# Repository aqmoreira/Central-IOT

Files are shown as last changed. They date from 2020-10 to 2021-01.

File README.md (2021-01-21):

# Central-IOT
Central Semafórica IOT - Projeto Hardware e Software UNIVESP

Projeto focado em explorar e praticar conceitos desenvolvidos no curso de Engenharia da Computação da UNIVESP, apresentado como projeto de TCC em Grupo.
<br>
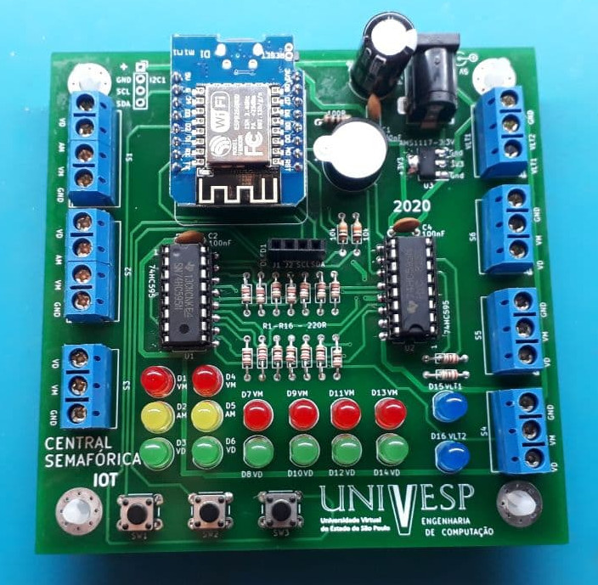
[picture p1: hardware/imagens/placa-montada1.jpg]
Placa Central IOT


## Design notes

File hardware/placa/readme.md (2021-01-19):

A placa foi desenvolvida com Kicad 5.1.6
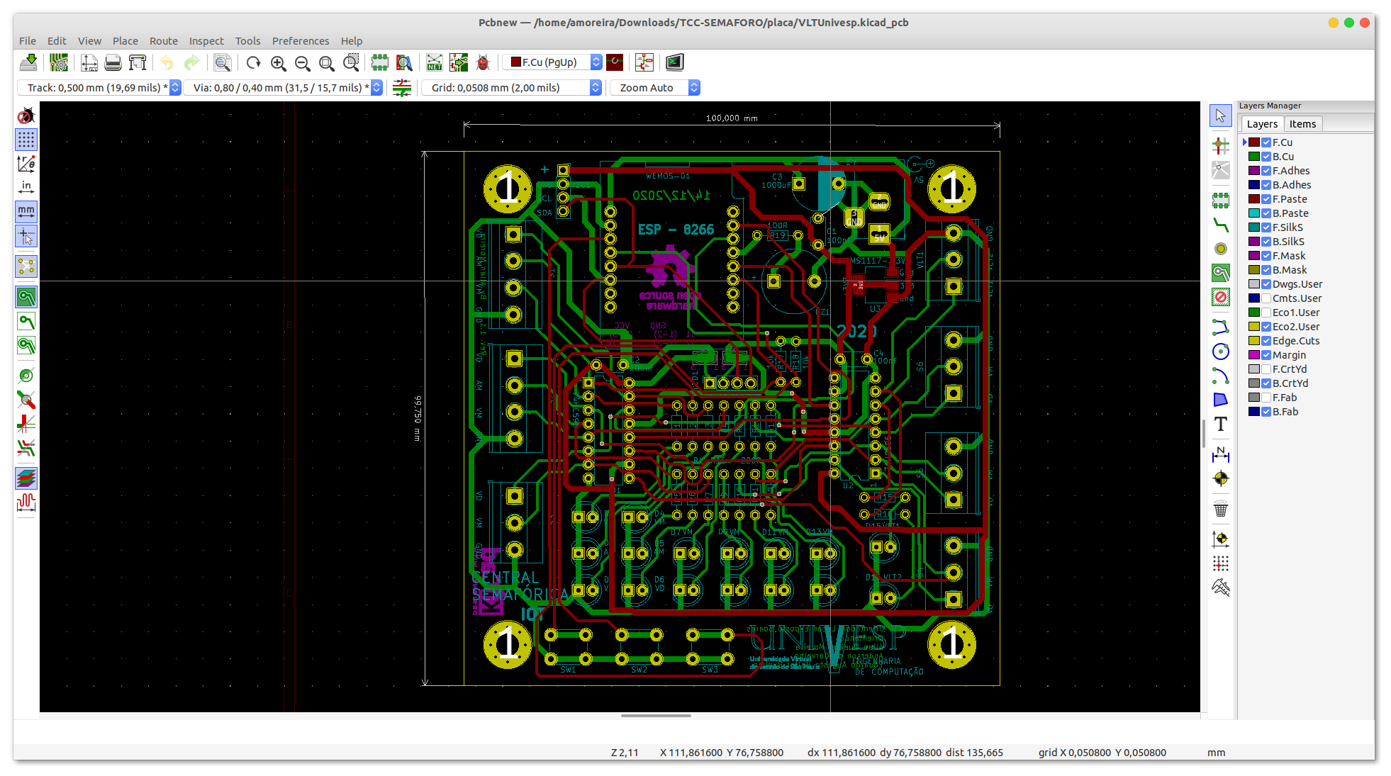
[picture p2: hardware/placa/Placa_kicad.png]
Imagem da Placa Kicad


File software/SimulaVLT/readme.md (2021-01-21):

Com objetivo de realizar os testes e simulação das diversas situações foi desenvolvido um simulador em HTML5.<br>
A implementação faz comunicação com um servidor Mqtt, simulando a movimentação do VLT pelo cruzamento.<br>
Para iniciar o simulador, realize o download dos arquivos da pasta e abra no Browser o arquivo index.html<br>

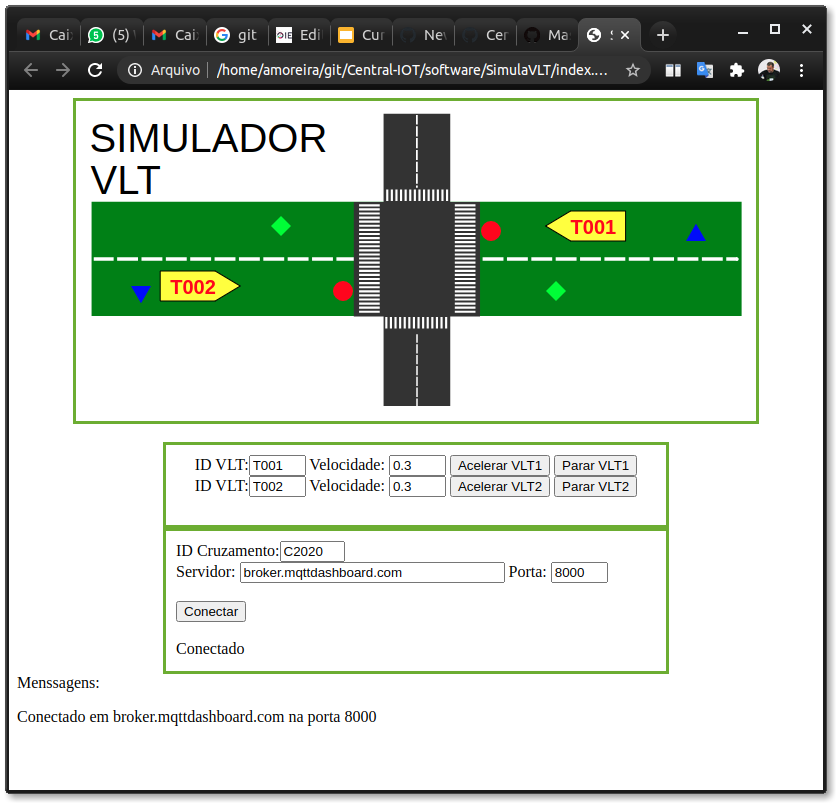
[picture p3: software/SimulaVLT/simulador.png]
Imagem da Simulador


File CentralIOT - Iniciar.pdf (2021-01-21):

1 - Instalar IDE Arduino
https://www.arduino.cc/en/software

2 - Adicionar suporte ao ESP8266,ESP32 a IDE Arduino

Abrir IDE Arduino e depois no menu Arquivo>Preferencias

Adicionar URL adicionais para gerenciamento de placas

https://arduino.esp8266.com/stable/package_esp8266com_index.json

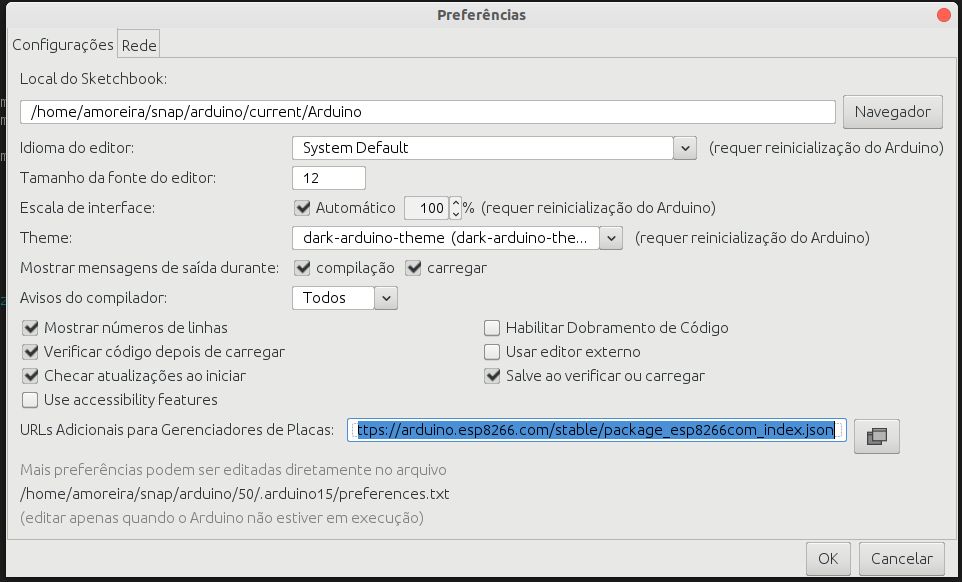
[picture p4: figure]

Aproveita e já marca as opções Mostrar mensagens de saída durante: compilação e carregar

3 - Adicionar pacote ESP8266
Menu Ferramentas > Placa:XXXX > Gerenciador de placas …

Pode informar esp no campo de filtro que vai listar apenas as relacionadas

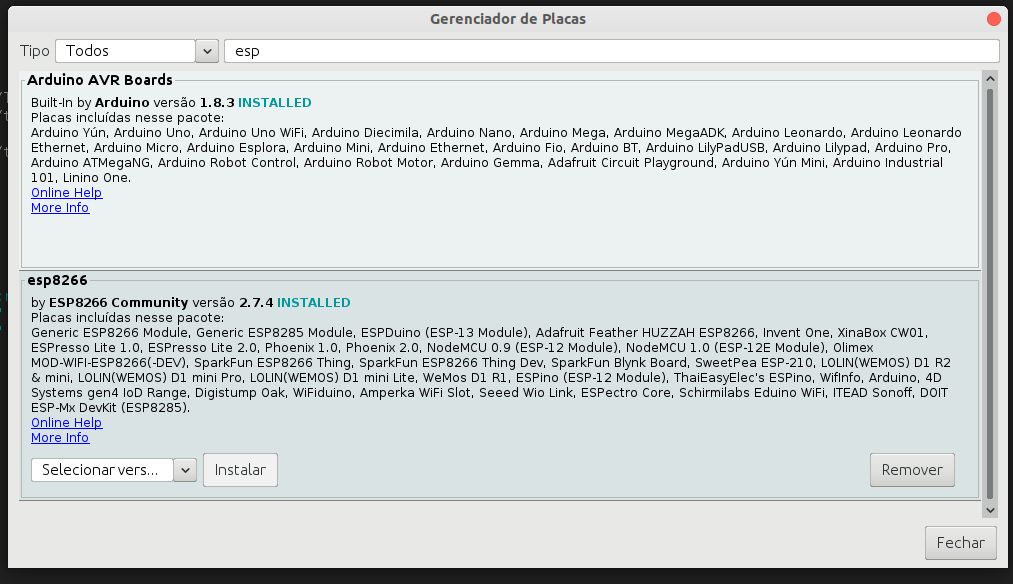
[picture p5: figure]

Deve instalar o ESP8266 Comunity, estou usando a versão 2.7.4

Ele vai carregar os pacotes para que a IDE do Arduino dê suporte aos diversos tipos de hardware do ESP.

4 - Selecionar qual placa estamos utilizando
Ferramentas -> Esp8266 2.7.4 > LOLIN (WEMOS) D1 R2 & mini

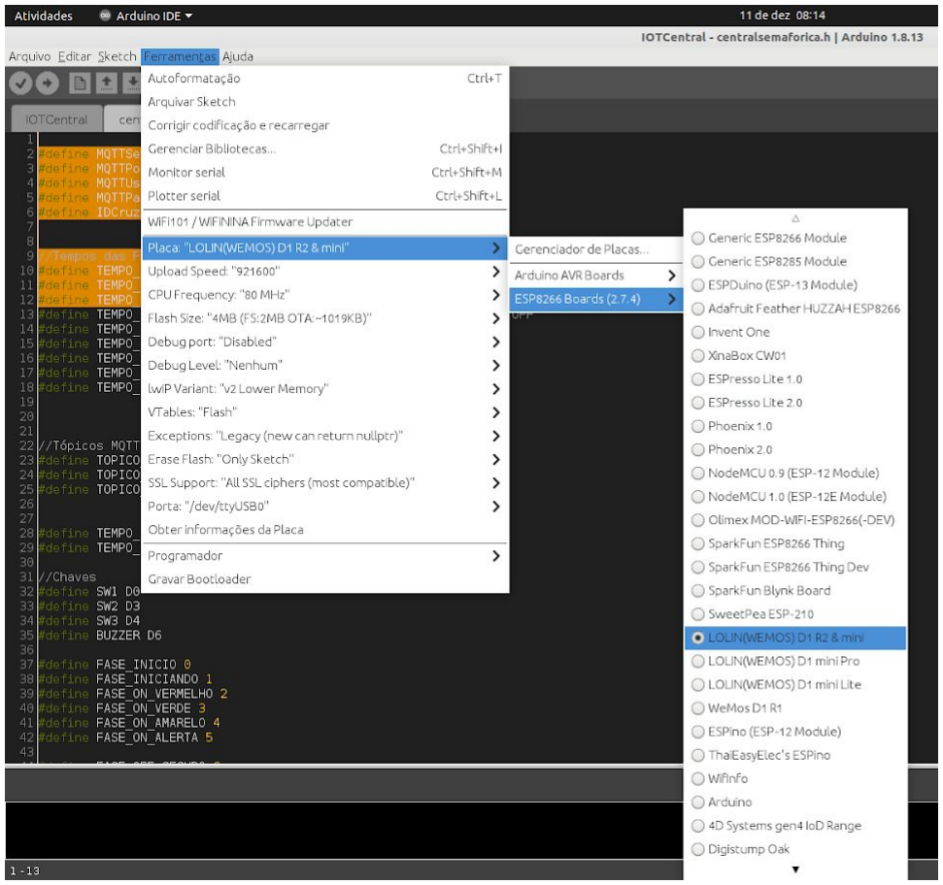
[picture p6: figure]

Esse processo faz apenas a primeira vez para selecionar a placa que está utilizando.

5 - Selecionar a porta serial.

Cada vez que conectar a placa na porta USB pode ser configurada uma porta serial virtual diferente, então deve se atentar a isso e selecionar a porta correta antes de carregar o firmware.

Ferramentas > Porta > Seleciona a porta que apareceu após você conectar

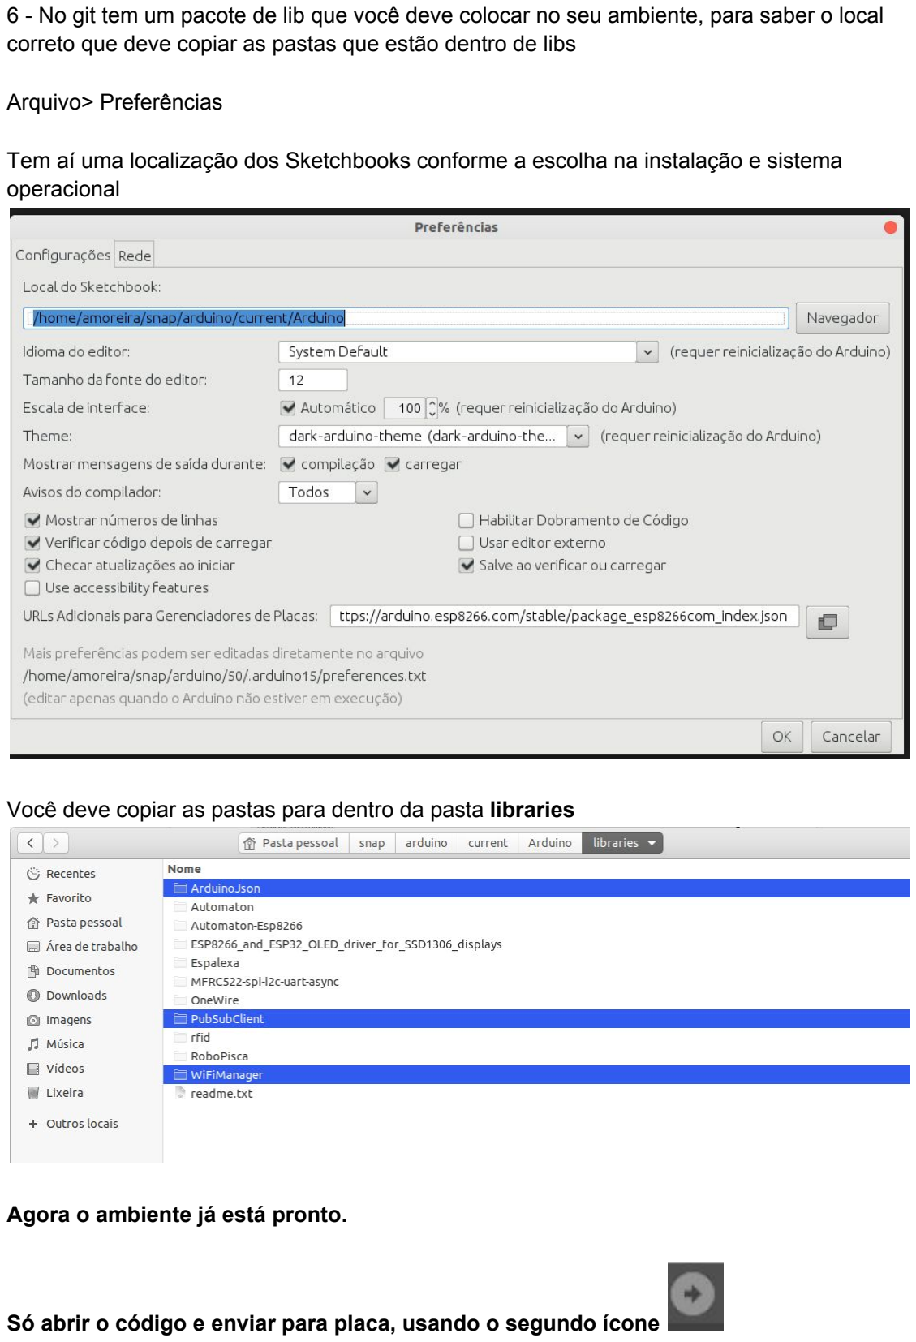
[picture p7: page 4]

6 - No git tem um pacote de lib que você deve colocar no seu ambiente, para saber o local correto que deve copiar as pastas que estão dentro de libs

Arquivo> Preferências

Tem aí uma localização dos Sketchbooks conforme a escolha na instalação e sistema operacional

Você deve copiar as pastas para dentro da pasta libraries

Agora o ambiente já está pronto.

Só abrir o código e enviar para placa, usando o segundo ícone

Fique atento na barra inferior se as mensagens com % de carregamento vai chegar a 100% ou se teremos algum erro.

Se o carregamento foi 100%, agora é reiniciar a placa no reset um pequeno botão perto do conector do cabo usb e manter pressionado a Sw1 e Sw3 para ele ligar uma rede chamada CentralIOT para vc conectar nela e fazer os ajustes da placa

Senha: univesp2020

Além dos dados da sua placa, você tem que informar id do cruzamento, por exemplo 0008, esse número vai aparecer depois no display para saber qual é o cruzamento que a placa está gerenciando

Os dados de Mqtt mantêm o padrão indicado que irá funcionar com esse servidor.

O servidor padrão você consegue acessar via browser:

http://www.hivemq.com/demos/websocket-client/?

Basta conectar e assinar os tópicos:

central/cruzamento/#
via01/+/<idcruzamento> //exemplo: via01/+/0008
via02/+/<idcruzamento>

COnectado na internet você vai ver no navegador chegando mensagem da placa em operação e para ver ela operando use o simulador abrindo a página no navegador que baixou do git

No simulador você deve colocar o idCruzamento igual da placa e conectar, e vai ver os eventos na placa, no servidor conforme o simulador opera.

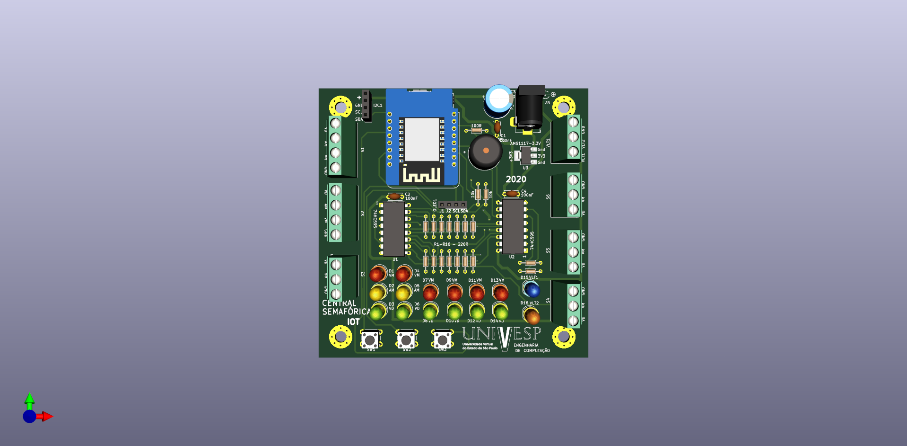
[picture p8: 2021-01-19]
hardware/placa/VLTUnivesp-frente.png

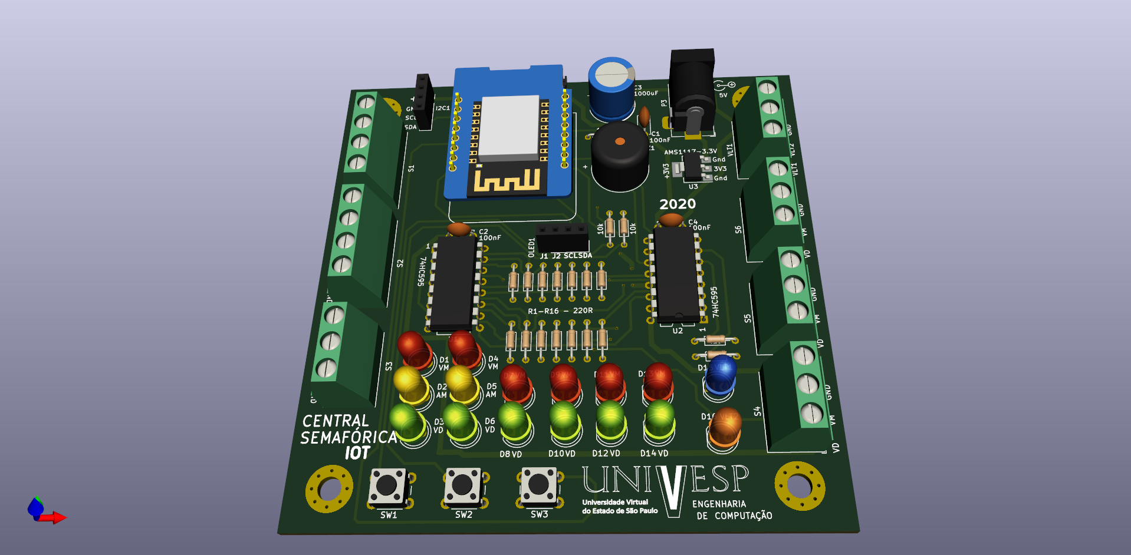
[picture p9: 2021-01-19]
hardware/placa/VLTUnivesp.png

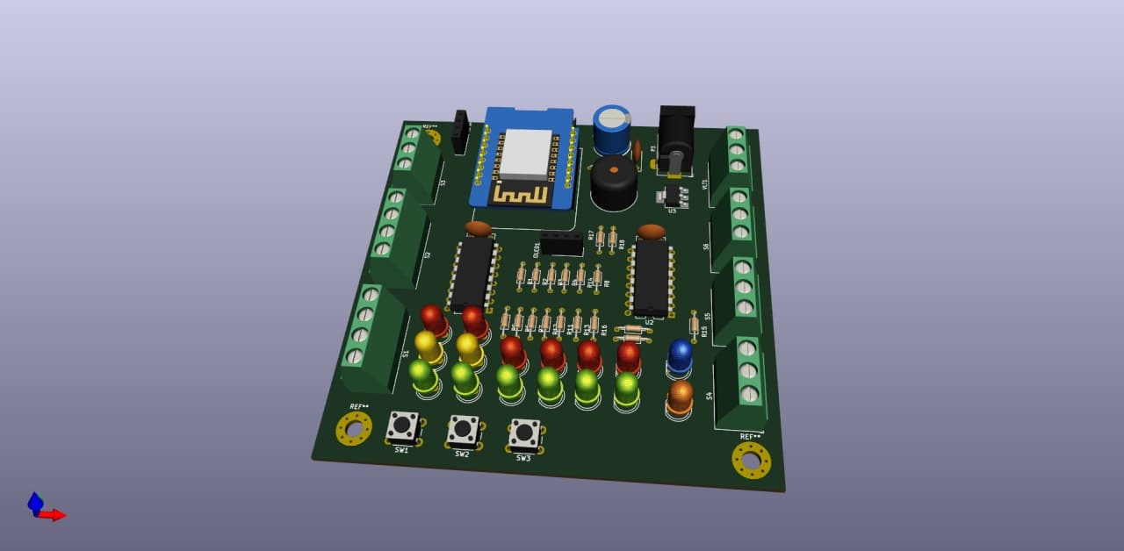
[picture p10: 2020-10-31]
hardware/imagens/central-iot-3d-kicad.jpg

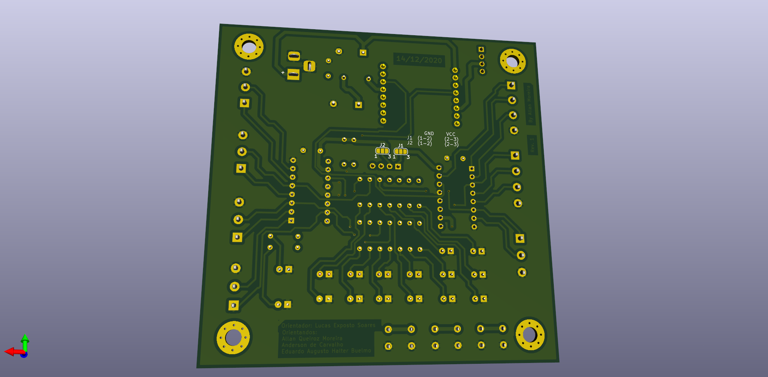
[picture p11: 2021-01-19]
hardware/placa/VLTUnivesp-verso.png

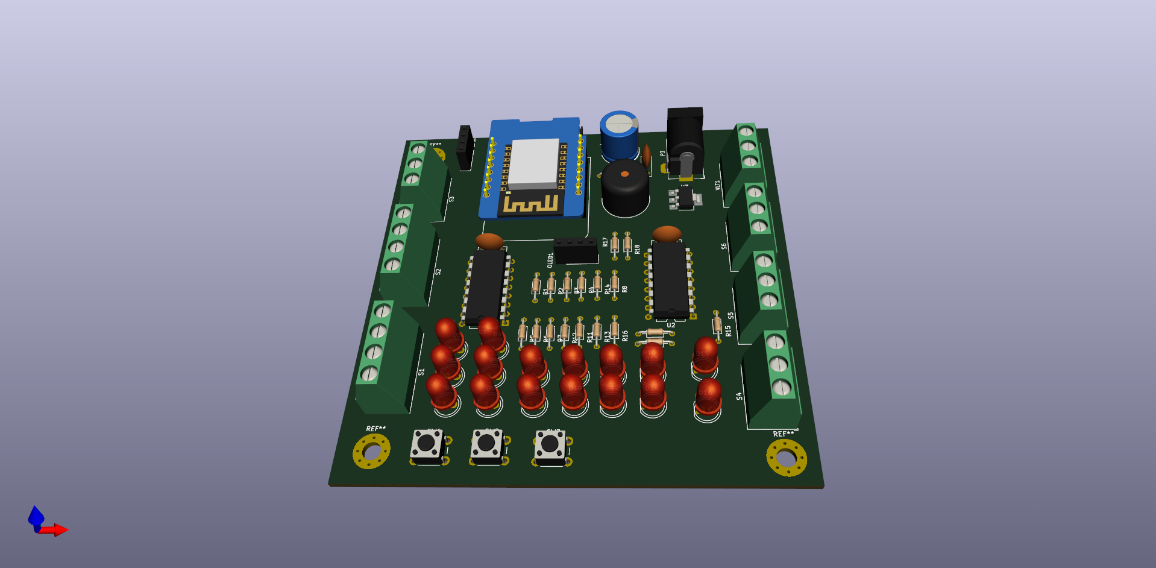
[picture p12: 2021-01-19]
hardware/placa/VLTUnivesp-frente1.png

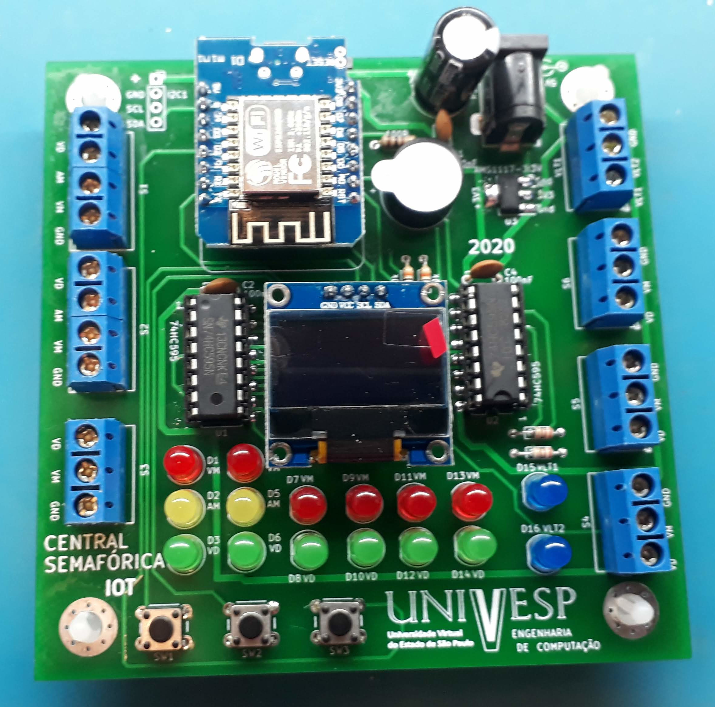
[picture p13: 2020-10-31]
hardware/imagens/placa-montada.jpg

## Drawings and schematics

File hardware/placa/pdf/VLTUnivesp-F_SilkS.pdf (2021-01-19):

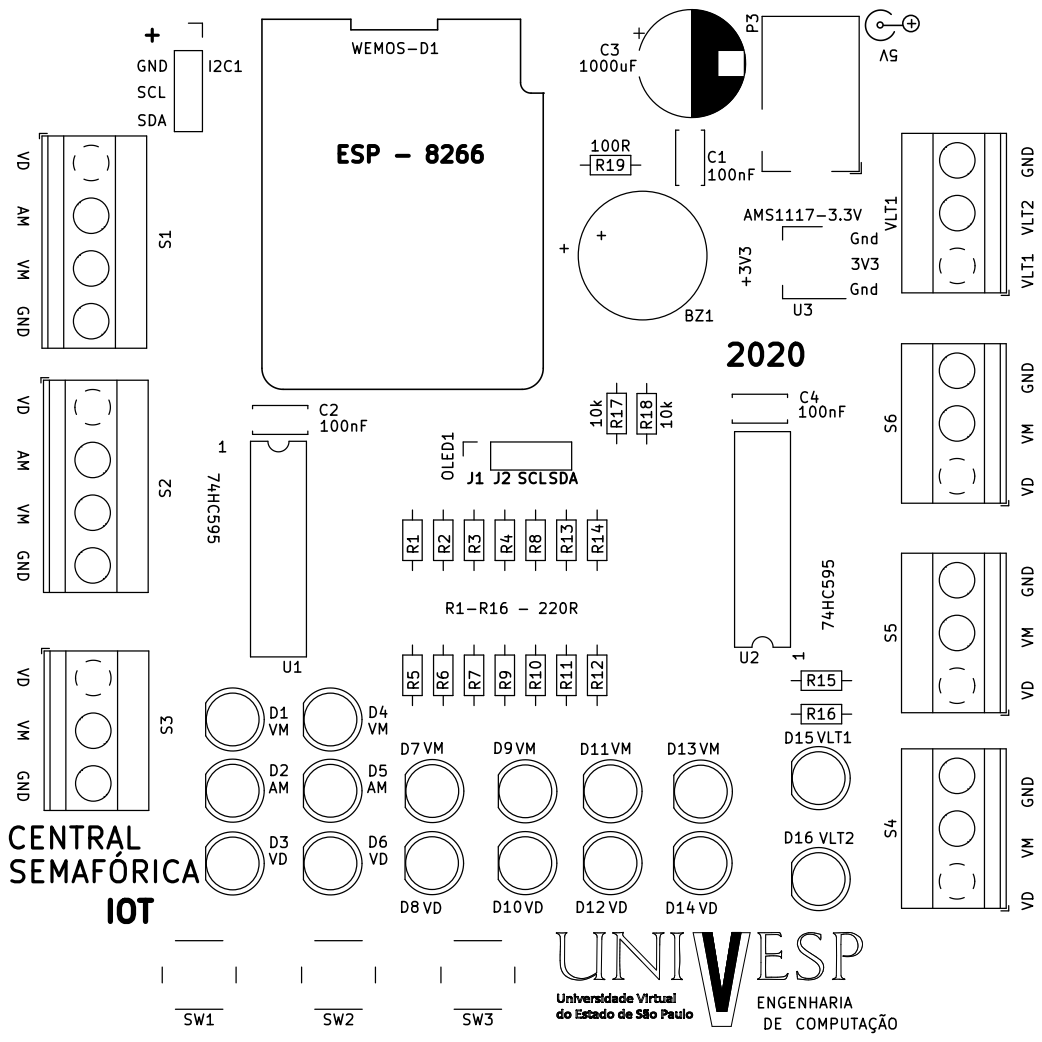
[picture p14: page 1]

VM GND VM VD VD GND VM AM GND VM AM VD

1 GND VLT2 VLT1 GND VD VM GND VM VD VD VM GND

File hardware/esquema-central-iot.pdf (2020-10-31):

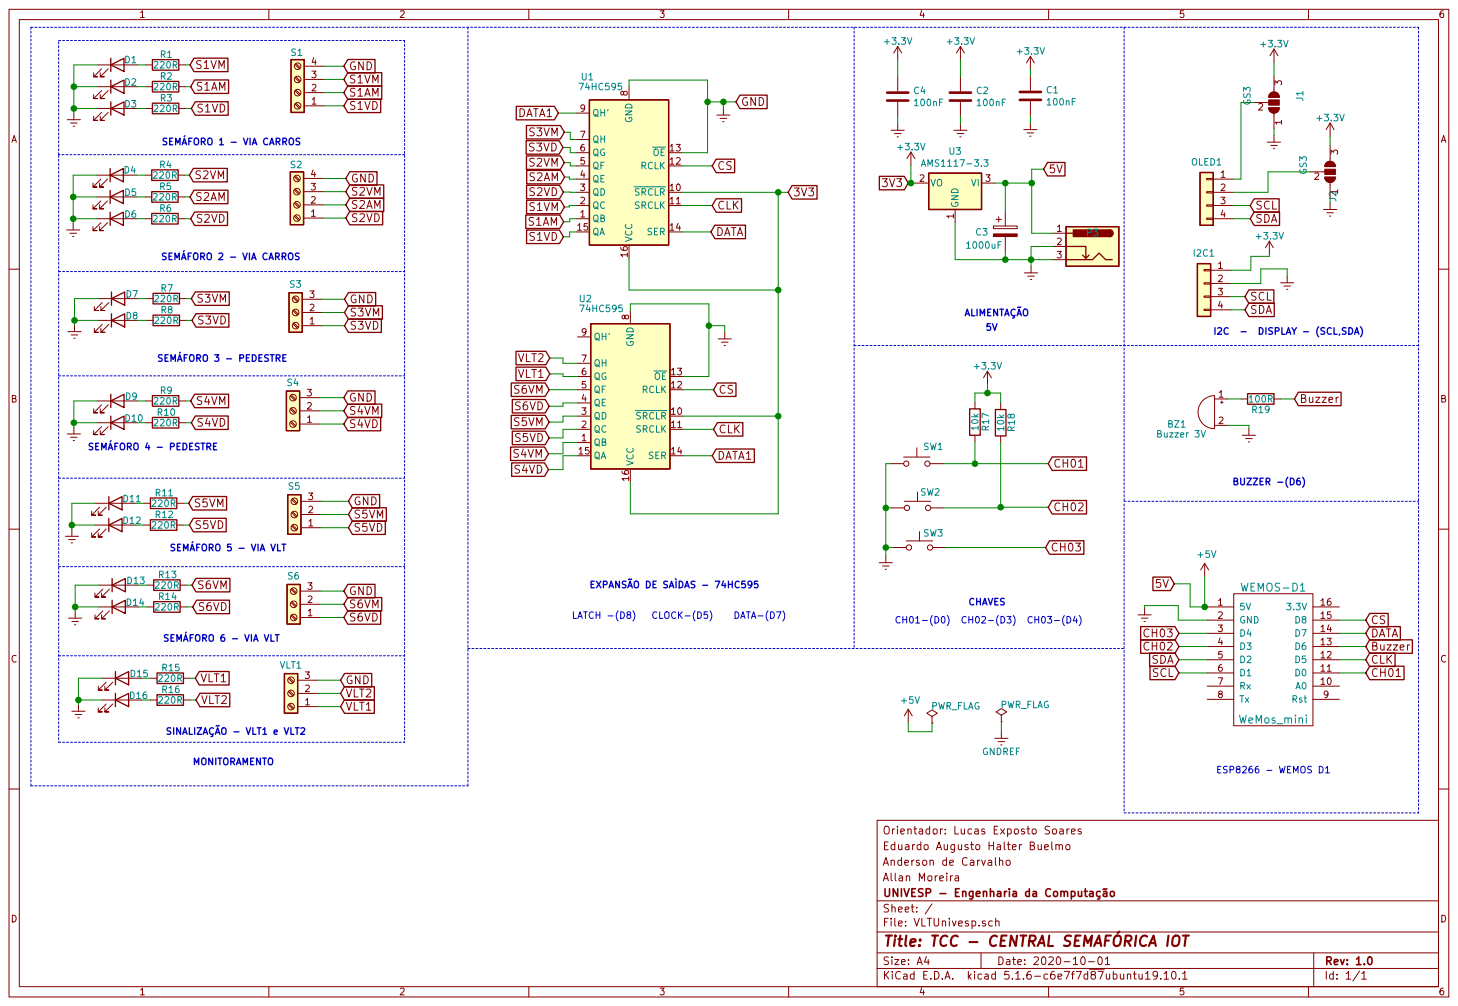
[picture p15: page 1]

SEMÁFORO 1 - VIA CARROS

SEMÁFORO 2 - VIA CARROS

SEMÁFORO 5 - VIA VLT MONITORAMENTO SEMÁFORO 6 - VIA VLT

SINALIZAÇÃO - VLT1 e VLT2

File: VLTUnivesp.sch Sheet: / UNIVESP - Engenharia da Computação Allan Moreira Anderson de Carvalho Eduardo Augusto Halter Buelmo

Id: 1/1 Title: TCC - CENTRAL SEMAFÓRICA IOT

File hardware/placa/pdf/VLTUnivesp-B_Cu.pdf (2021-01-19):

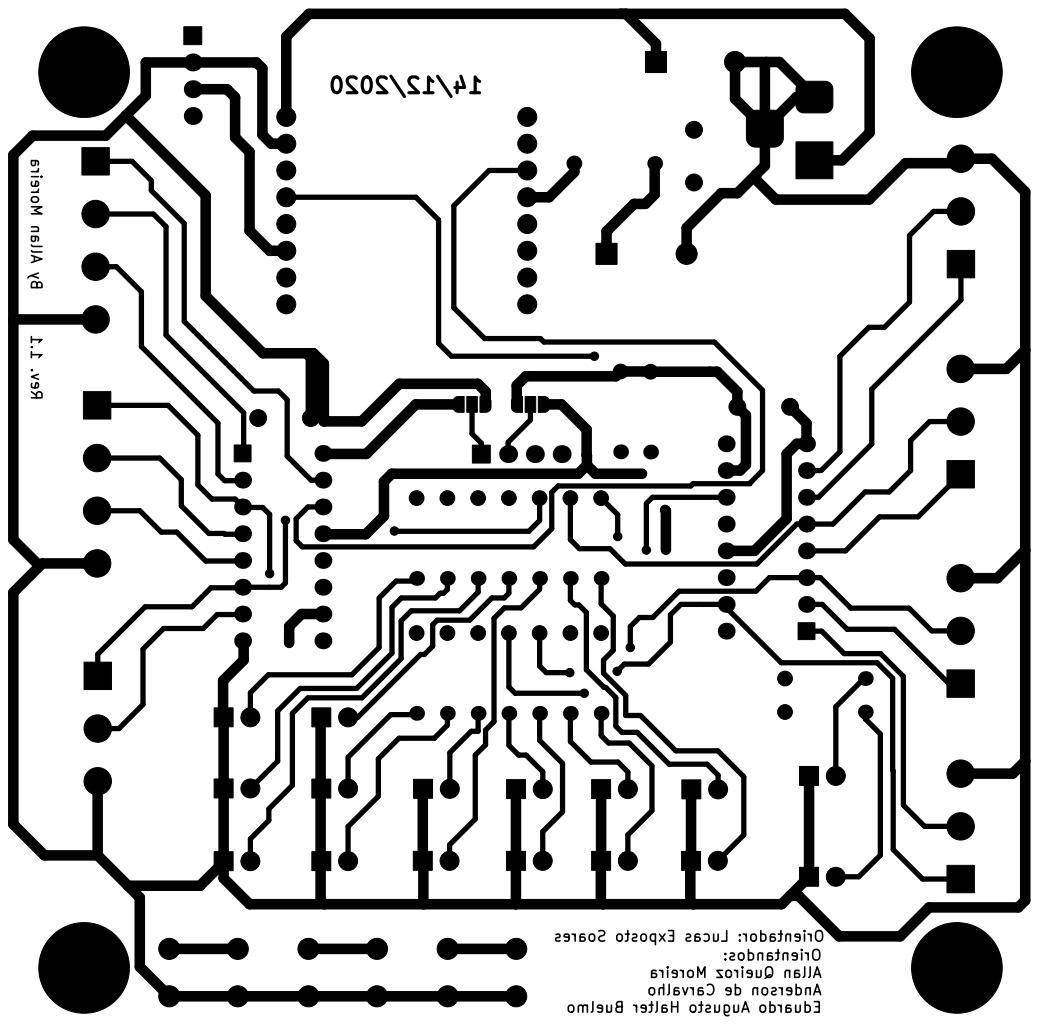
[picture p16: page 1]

14/12/2020 Rev. 1.1 By Allan Moreira Orientandos: Allan Queiroz Moreira Anderson de Carvalho Eduardo Augusto Halter Buelmo Orientador: Lucas Exposto Soares

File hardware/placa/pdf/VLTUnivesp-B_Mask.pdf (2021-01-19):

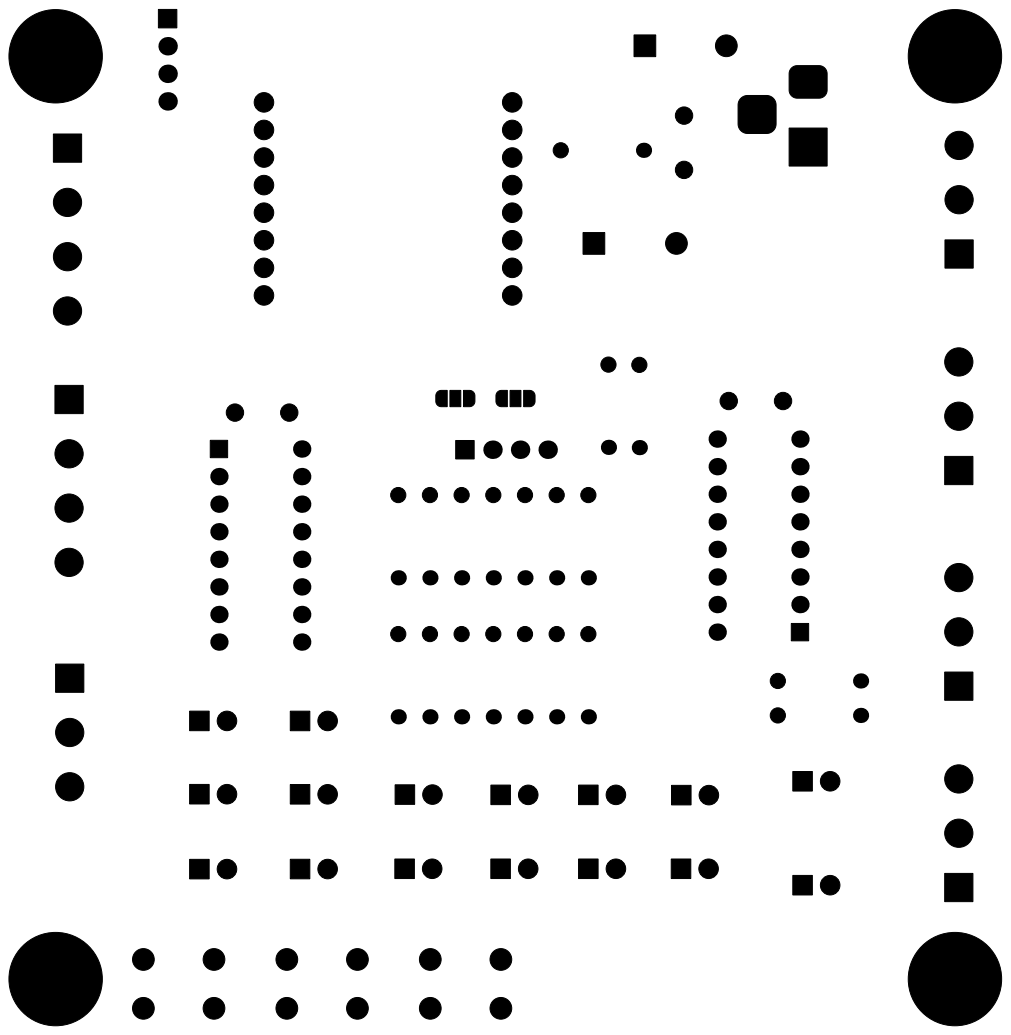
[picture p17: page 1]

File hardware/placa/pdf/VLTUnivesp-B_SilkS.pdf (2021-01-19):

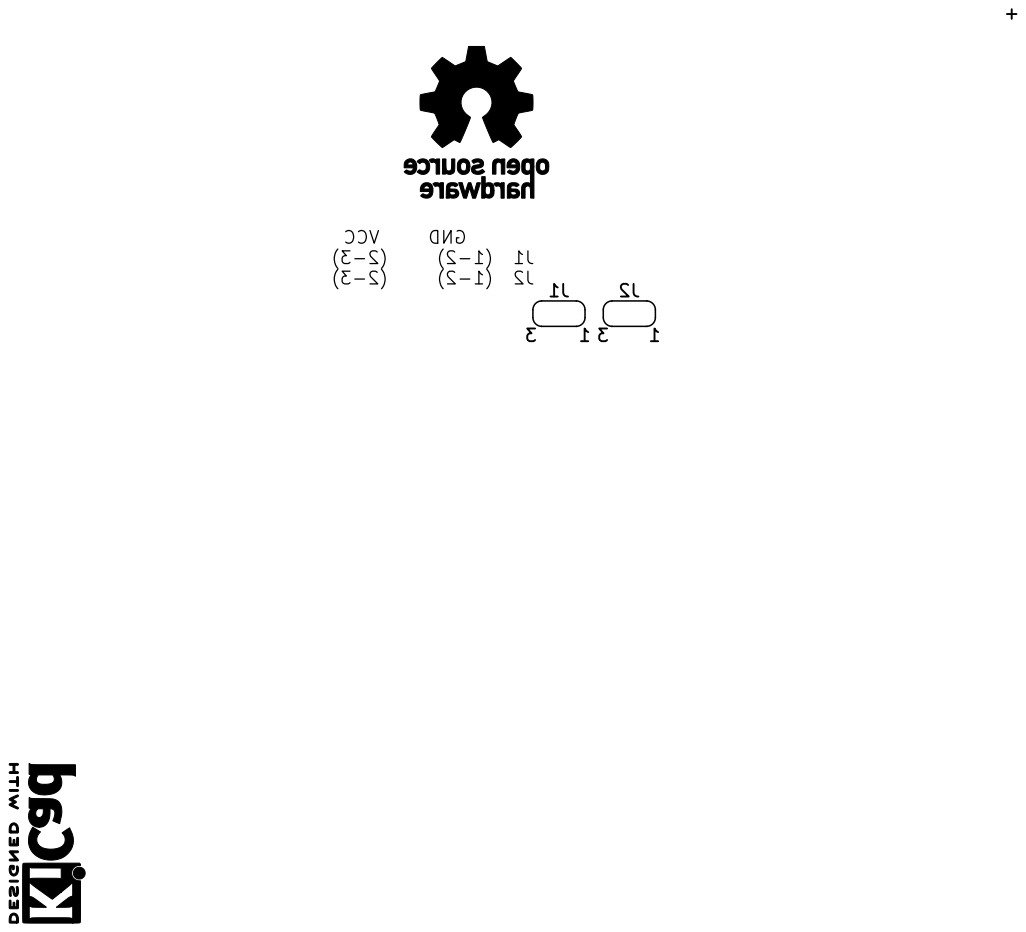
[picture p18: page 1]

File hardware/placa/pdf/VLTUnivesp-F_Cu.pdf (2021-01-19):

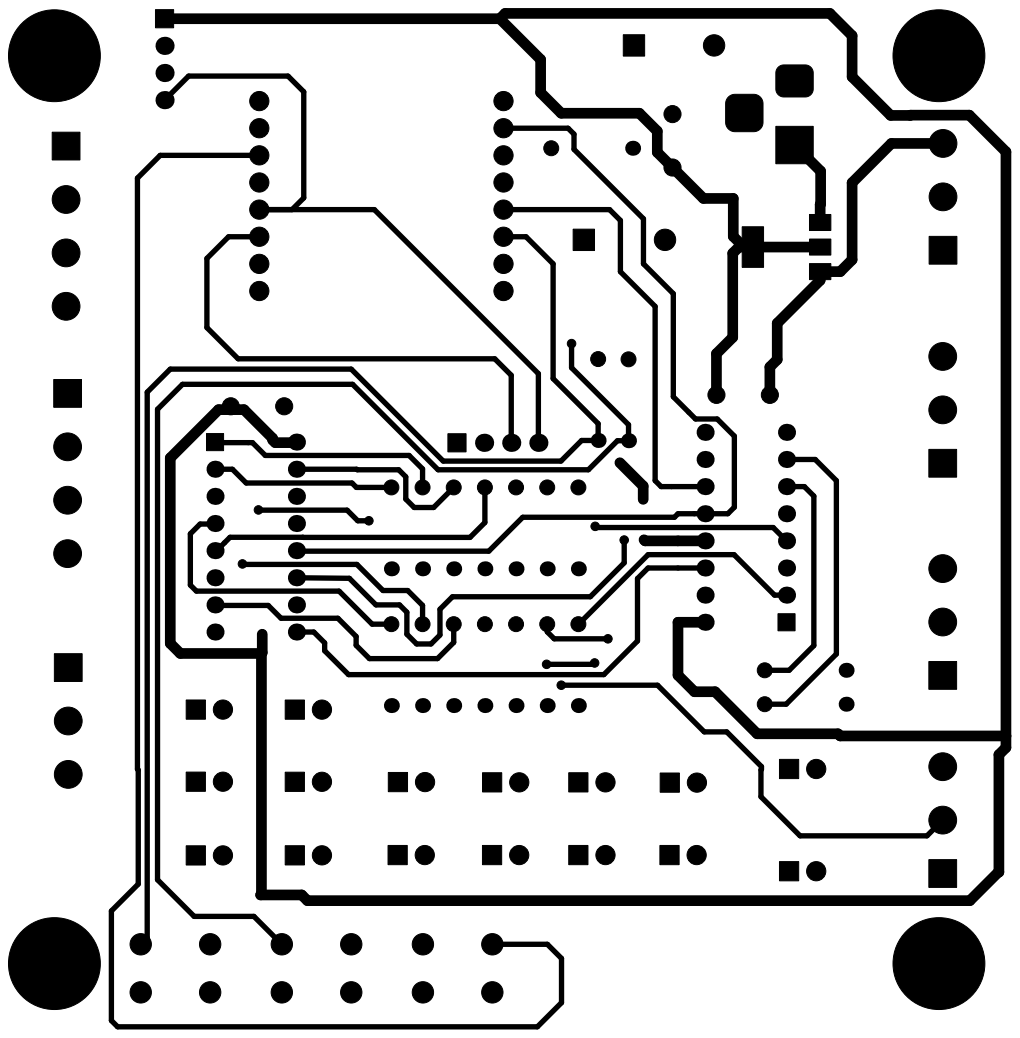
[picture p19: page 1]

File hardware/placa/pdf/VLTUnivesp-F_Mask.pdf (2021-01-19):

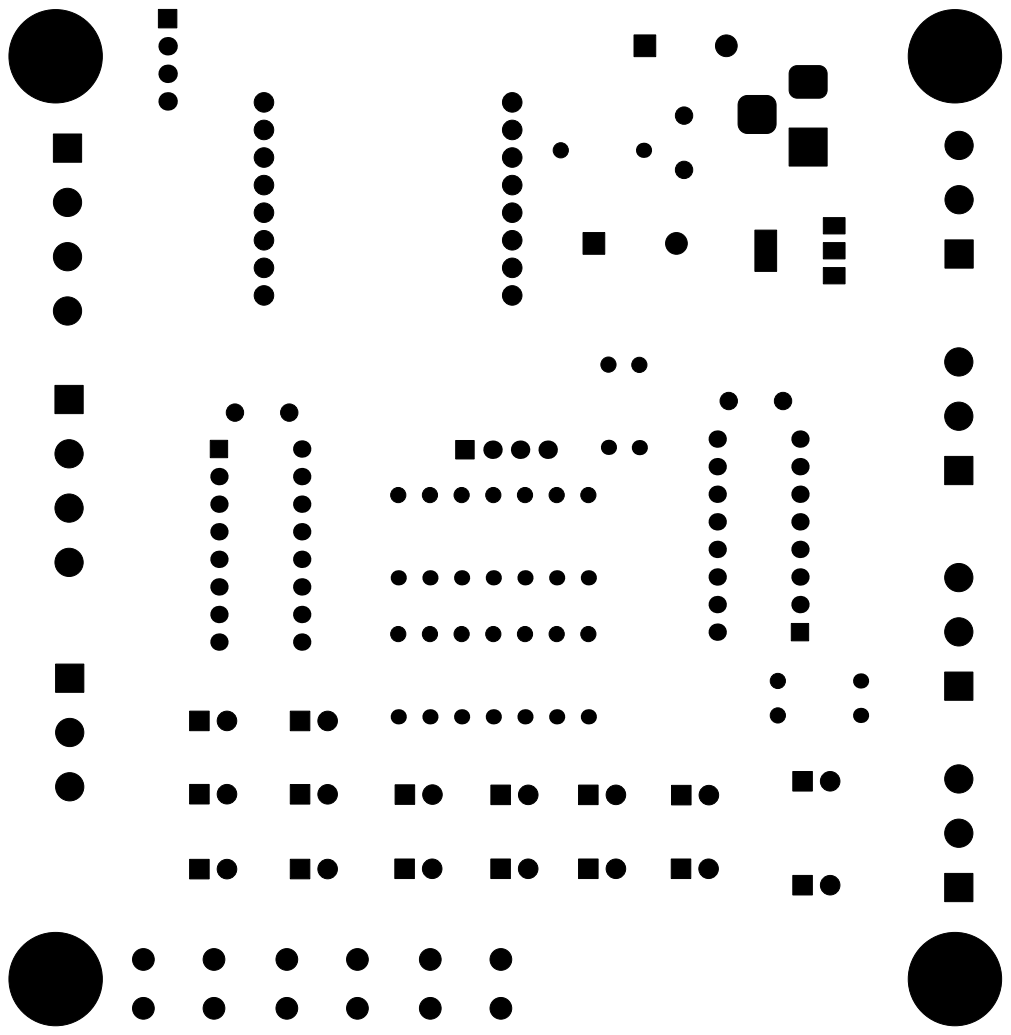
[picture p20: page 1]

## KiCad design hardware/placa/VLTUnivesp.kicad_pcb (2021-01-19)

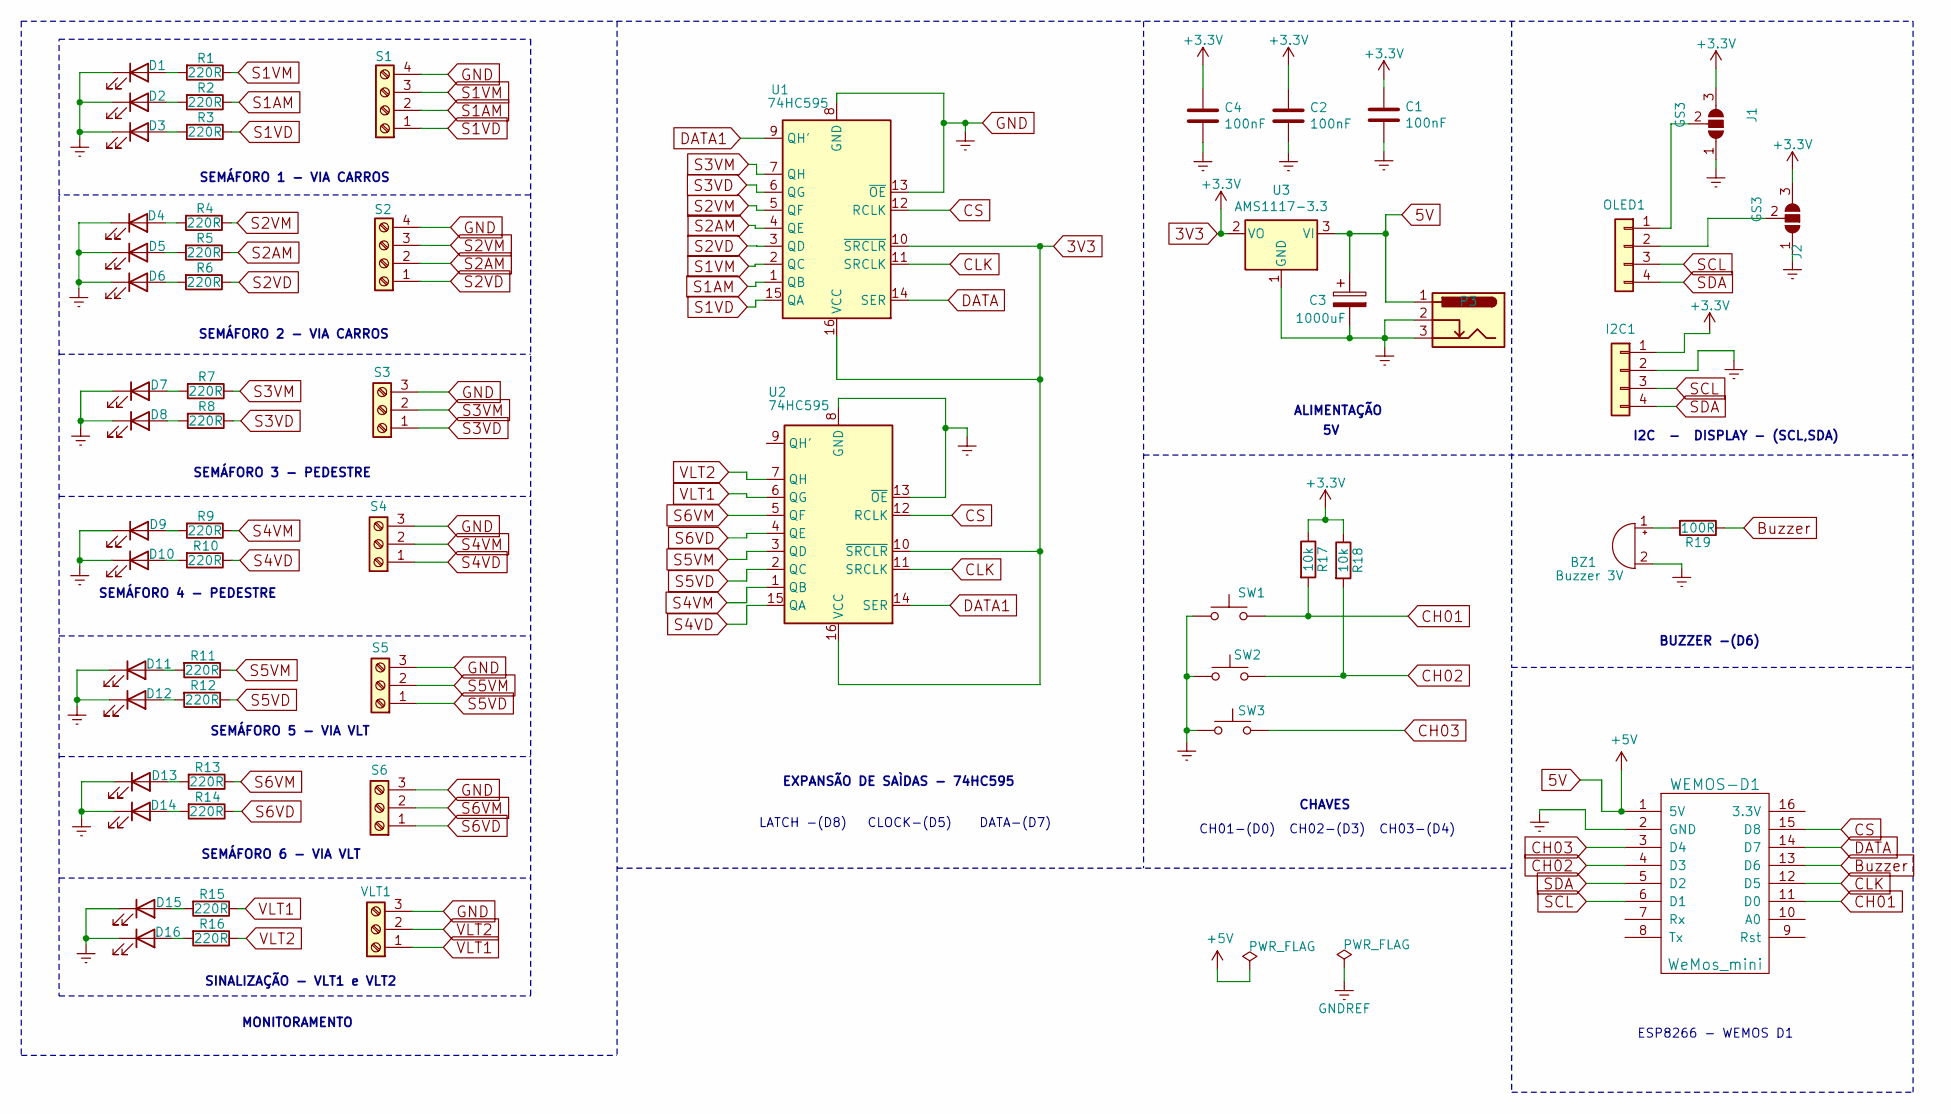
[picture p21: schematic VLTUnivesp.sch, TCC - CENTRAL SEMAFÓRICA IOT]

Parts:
BZ1: Buzzer 3V; Buzzer_12x9.5RM7.6
C1, C2, C4: 100nF; C_Disc_D5.0mm_W2.5mm_P5.00mm
C3: 1000uF; CP_Radial_D10.0mm_P7.50mm
D1, D4, D7, D9, D11, D13: LED; LED_D5.0mm_VM
D2, D5: LED; LED_D5.0mm_AM
D3, D6, D8, D10, D12, D14: LED; LED_D5.0mm_VD
D15: LED; LED_D5.0mm_AZ
D16: LED; LED_D5.0mm_LA
I2C1: CONN_01X04; PinSocket_1x04_P2.54mm_Vertical
J1, J2: GS3; SolderJumper-3_P1.3mm_Open_RoundedPad1.0x1.5mm_NumberLabels
OLED1: CONN_01X04; PinSocket_1x04_P2.54mm_Vertical
P3: CONN_01X03; BarrelJack_Horizontal
R1, R2, R3, R4, R5, R6, R7, R8, R9, R10, R11, R12, R13, R14, R15, R16: 220R; R_Axial_DIN0204_L3.6mm_D1.6mm_P7.62mm_Horizontal
R17, R18: 10k; R_Axial_DIN0204_L3.6mm_D1.6mm_P7.62mm_Horizontal
R19: 100R; R_Axial_DIN0204_L3.6mm_D1.6mm_P7.62mm_Horizontal
S1, S2: Screw_Terminal_01x04; KRE-1x04_P5.00mm_Horizontal
S3, S4, S5, S6: Screw_Terminal_01x03; KRE-1x03_P5.00mm_Horizontal
SW1, SW2, SW3: SW_PUSH; SW_PUSH_6mm
U1, U2: 74HC595; DIP-16_W7.62mm
U3: AMS1117-3.3; SOT-223-3_TabPin2
VLT1: Screw_Terminal_01x03; KRE-1x03_P5.00mm_Horizontal
WEMOS-D1: WeMos_mini; wemos-d1-mini-with-pin-header-and-connector

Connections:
3V3: C1.1, C2.1, C4.1, I2C1.1, J1.3 (B), J2.3 (B), R17.1, R18.1, U1.10 (~SRCLR), U1.16 (VCC), U2.10 (~SRCLR), U2.16 (VCC), U3.2 (VO)
5V: C3.1, P3.1, U3.3 (VI), WEMOS-D1.1 (5V)
Buzzer: R19.1, WEMOS-D1.13 (D6)
CH01: R17.2, SW1.2, WEMOS-D1.11 (D0)
CH02: R18.2, SW2.2, WEMOS-D1.4 (D3)
CH03: SW3.2, WEMOS-D1.3 (D4)
CLK: U1.11 (SRCLK), U2.11 (SRCLK), WEMOS-D1.12 (D5)
CS: U1.12 (RCLK), U2.12 (RCLK), WEMOS-D1.15 (D8)
DATA: U1.14 (SER), WEMOS-D1.14 (D7)
DATA1: U1.9 (QH'), U2.14 (SER)
GND: BZ1.2 (+), C1.2, C2.2, C3.2, C4.2, D1.1 (K), D2.1 (K), D3.1 (K), D4.1 (K), D5.1 (K), D6.1 (K), D7.1 (K), D8.1 (K), D9.1 (K), D10.1 (K), D11.1 (K), D12.1 (K), D13.1 (K), D14.1 (K), D15.1 (K), D16.1 (K), I2C1.2, J1.1 (A), J2.1 (A), P3.2, P3.3, S1.4, S2.4, S3.3, S4.3, S5.3, S6.3, SW1.1, SW2.1, SW3.1, U1.8 (GND), U1.13 (~OE), U2.8 (GND), U2.13 (~OE), U3.1 (GND), VLT1.3, WEMOS-D1.2 (GND)
unnamed: BZ1.1 (-), R19.2
unnamed: D1.2 (A), R1.2
unnamed: D2.2 (A), R2.2
unnamed: D3.2 (A), R3.2
unnamed: D4.2 (A), R4.2
unnamed: D5.2 (A), R5.2
unnamed: D6.2 (A), R6.2
unnamed: D7.2 (A), R7.2
unnamed: D8.2 (A), R8.2
unnamed: D9.2 (A), R9.2
unnamed: D10.2 (A), R10.2
unnamed: D11.2 (A), R11.2
unnamed: D12.2 (A), R12.2
unnamed: D13.2 (A), R13.2
unnamed: D14.2 (A), R14.2
unnamed: D15.2 (A), R15.2
unnamed: D16.2 (A), R16.2
unnamed: J1.2 (C), OLED1.1
unnamed: J2.2 (C), OLED1.2
S1AM: R2.1, S1.2, U1.1 (QB)
S1VD: R3.1, S1.1, U1.15 (QA)
S1VM: R1.1, S1.3, U1.2 (QC)
S2AM: R5.1, S2.2, U1.4 (QE)
S2VD: R6.1, S2.1, U1.3 (QD)
S2VM: R4.1, S2.3, U1.5 (QF)
S3VD: R8.1, S3.1, U1.6 (QG)
S3VM: R7.1, S3.2, U1.7 (QH)
S4VD: R10.1, S4.1, U2.15 (QA)
S4VM: R9.1, S4.2, U2.1 (QB)
S5VD: R12.1, S5.1, U2.2 (QC)
S5VM: R11.1, S5.2, U2.3 (QD)
S6VD: R14.1, S6.1, U2.4 (QE)
S6VM: R13.1, S6.2, U2.5 (QF)
SCL: I2C1.3, OLED1.3, WEMOS-D1.6 (D1)
SDA: I2C1.4, OLED1.4, WEMOS-D1.5 (D2)
VLT1: R15.1, U2.6 (QG), VLT1.1
VLT2: R16.1, U2.7 (QH), VLT1.2

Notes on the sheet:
I2C - DISPLAY - (SCL,SDA)
BUZZER -(D6)
ESP8266 - WEMOS D1
ALIMENTAÇÃO
CHAVES
SEMÁFORO 1 - VIA CARROS
SEMÁFORO 2 - VIA CARROS
SEMÁFORO 3 - PEDESTRE
SEMÁFORO 4 - PEDESTRE
SEMÁFORO 5 - VIA VLT
SEMÁFORO 6 - VIA VLT
SINALIZAÇÃO - VLT1 e VLT2
MONITORAMENTO
EXPANSÃO DE SAÌDAS - 74HC595
CH01-(D0) CH02-(D3) CH03-(D4)
LATCH -(D8) CLOCK-(D5) DATA-(D7)

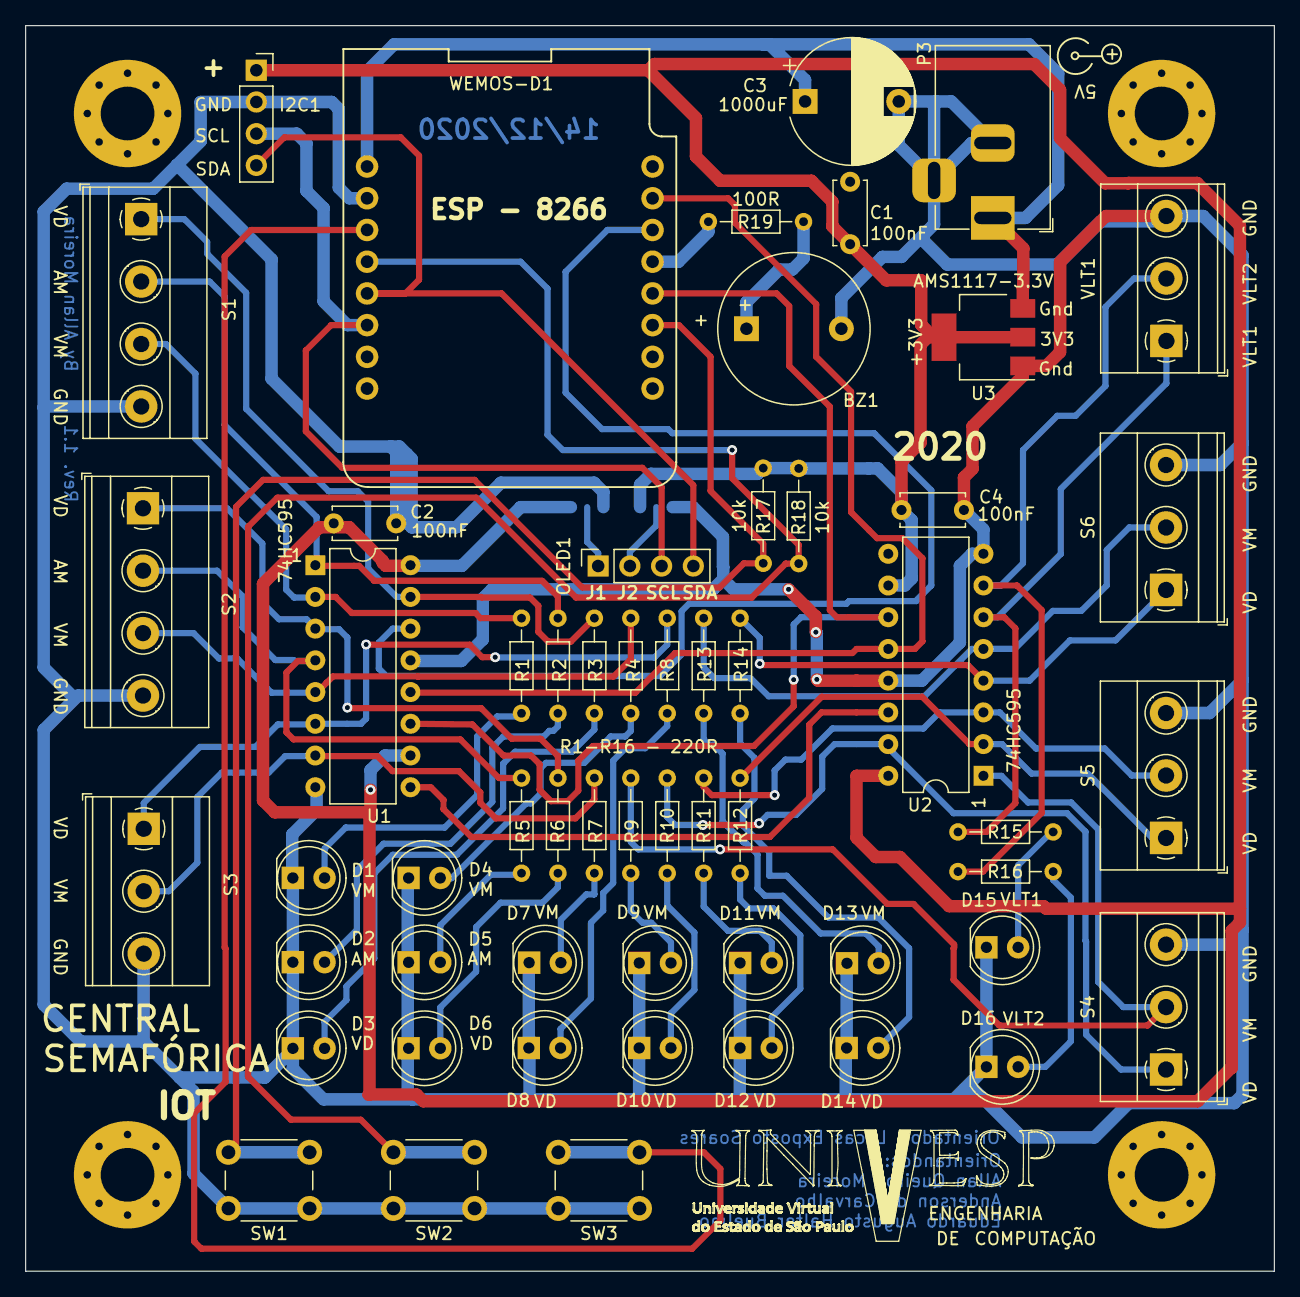
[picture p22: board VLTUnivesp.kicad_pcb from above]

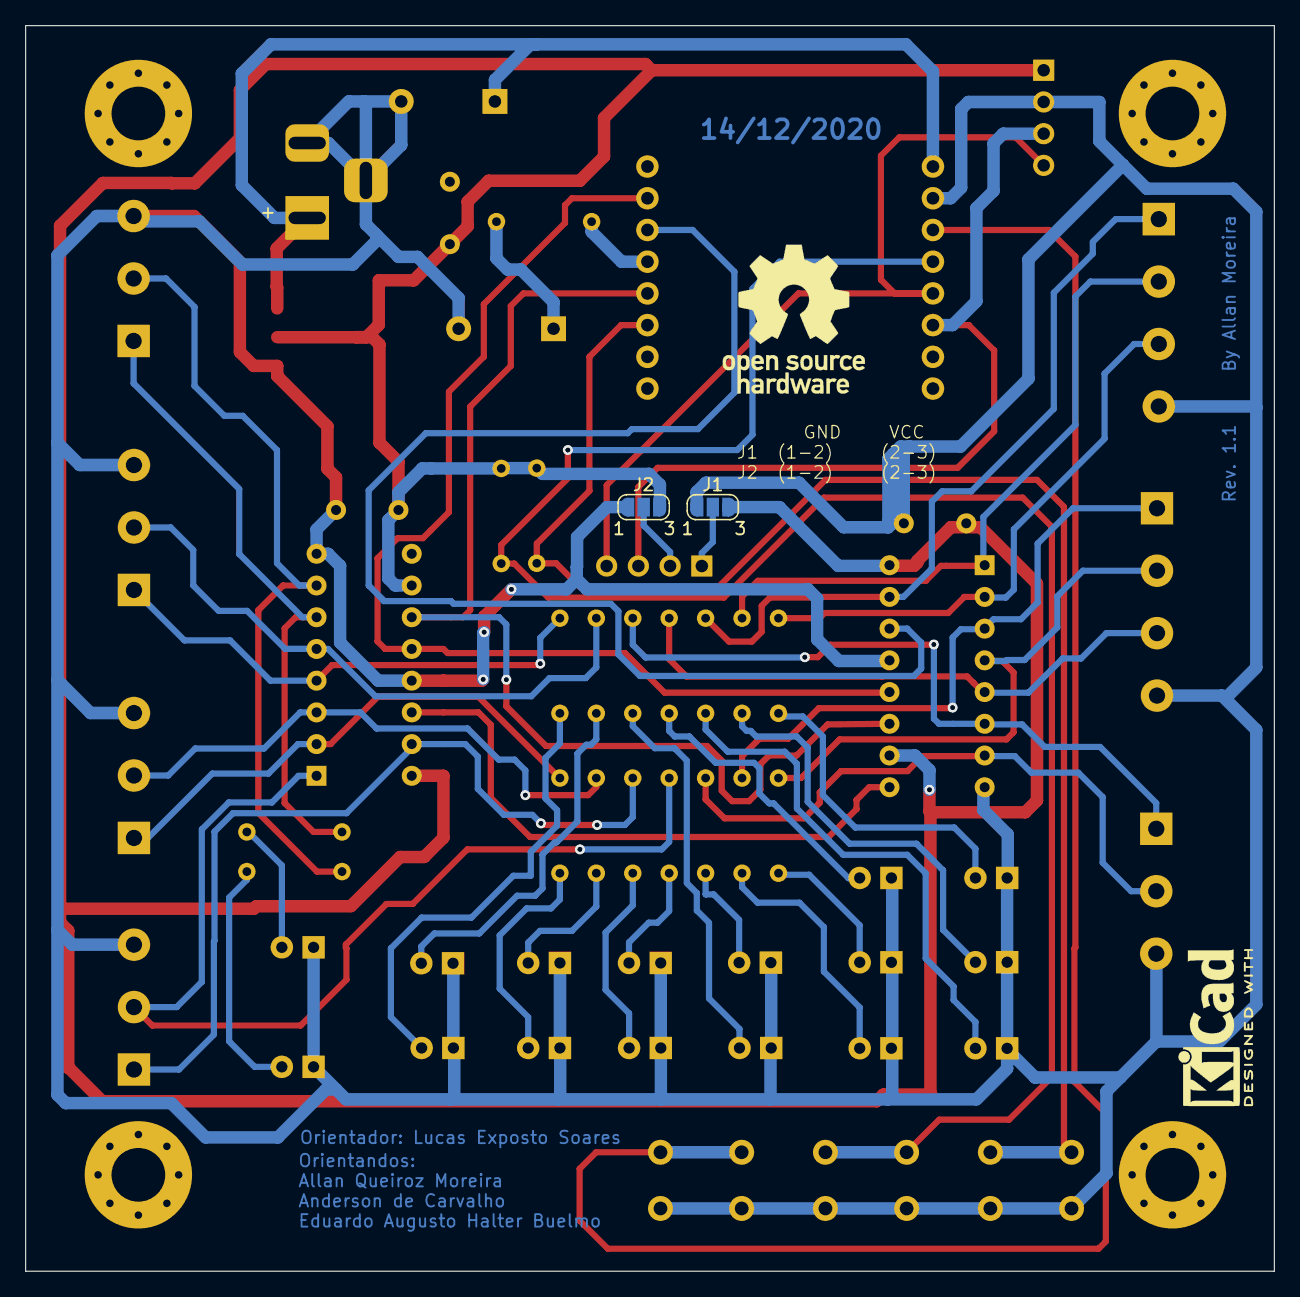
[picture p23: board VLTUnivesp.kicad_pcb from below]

Board: 2 copper layers, 100.0 x 99.8 mm, 59 parts (2 on the bottom side), 48 nets.

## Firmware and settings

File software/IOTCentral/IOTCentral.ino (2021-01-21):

/**
   Central Semafórica IOT
   Controla cruzamento secundário, dando prioridade ao VLT
   Se estiver sem conexão atua de forma offline com tempos pré definidos

 * */

#include <FS.h>          // Isso precisa estar em primeiro para evitar erros no sistema de arquivos
#include <WiFiManager.h> // https://github.com/tzapu/WiFiManager V 2.0.3-alpha
#include <ArduinoJson.h> // https://github.com/bblanchon/ArduinoJson V5.13.5
#include <SPI.h>
#include <Wire.h>               // Only needed for Arduino 1.6.5 and earlier
#include<ESP8266WiFi.h>       //Esp8266 Boards 2.7.4
#include <PubSubClient.h>    //https://github.com/knolleary/pubsubclient/releases/tag/v2.8
#include "src/ssd1306/SSD1306Wire.h"        //  #include "SSD1306.h" // https://github.com/ThingPulse/esp8266-oled-ssd1306
#include "centralsemaforica.h"
#include "imagens.h"



// Initialize the OLED display using Arduino Wire:
SSD1306Wire display(0x3c, SDA, SCL);

const int CSpino = D8; // Pino CS 74HC595



//T2 T1 VM VD VM VD VM VD - Byte Superior
//VM VD VM AM VD VM AM VD - Byte Inferior
uint16_t semaforo = 0x0000;         //Status dos Leds cada bit em 1, acende



//Tempos de monitoração
unsigned long tempoMaxCruzamentoVia = TEMPO_MAXIMO_CRUZAMENTO_VIA;//Tempo para VLT cruzar via Vermelho Rua
unsigned long tempoMaxVerde = TEMPO_MAXIMO_VERDE;        //Tempo máximo verde - Mesmo Online
unsigned long tempoAlerta = TEMPO_ALERTA;          //Tempo alerta de mundaça de sinal via
unsigned long tempoAmarelo = TEMPO_AMARELO;         //Tempo Amarelo
unsigned long tempoSeguranca = TEMPO_SEGURANCA;       //Tempo de Segurança qdo fica sem conexão e mudar fase
unsigned long tempoVerde = TEMPO_VERDE;           //Tempo Verde

unsigned long tempoMaxEsperaVLT = TEMPO_MAXIMO_ESPERA_VLT;    //Tempo máximo VLT fica esperando
unsigned long tempoMinVerde = TEMPO_MINIMO_VERDE;        //Tempo mínimo verde de fluxo rua
unsigned long tempoAlertaPiscante = TEMPO_ALERTA_PISCANTE;  //tempo que fica piscando pedestre e via na mudança de fase


unsigned long tempoAtual = 0;            //variável para usar de rascunho do tempo atual
unsigned long tempoTrocadoManutencao = 0; //armazena o tempo em milis que foi feita ultima troca
unsigned long tempoTrocadoPedestre = 0; //armazena o tempo em milis que foi feita ultima troca
unsigned long tempoTrocadoVia = 0; //armazena o tempo em milis que foi feita ultima troca
unsigned long tempoTrocadoVLT = 0; //armazena o tempo em milis que foi feita ultima troca da sinalização VLT

unsigned long tempoRefreshRelogio = 0; //de qto tempo relógio deve ser acertado

//Inicializa com valores defaul, se for diferente do valores gravados em config serão alterados
char mqttServer[40] =  MQTTServer;
char mqttPort[6]  = MQTTPort;
char mqttUser[20]  = MQTTUser;
char mqttPass[20]  = MQTTPass;
char idCruzamento[5] = IDCruzamento;

WiFiClient espClient; // Cria o objeto espClient
PubSubClient mqtt(espClient); // Instancia o Cliente MQTT passando o objeto espClient


String topicoCruzamento ;    //tópico de publocação status central/cruzamento/<idCruzamento>



const char* statusCentral = "Ativo e operando";

WiFiEventHandler gotIpEventHandler, disconnectedEventHandler;

//flag para informa se deve salvar propriedades
bool salvarPropriedades = false;


WiFiManager wm; // WiFiManager

unsigned long contadorEspera = 0;


// Status das conexões WiFi e MQTT:
//
// status |   WiFi   |    MQTT
// -------+----------+------------
//      0 |   OFF    |    OFF
//      1 | Iniciando|    OFF
//      2 |    ON    |    OFF
//      3 |    ON    |  Iniciando
//      4 |    ON    | Registrando
//      5 |    ON    |     ON
uint8_t statusConexao = 0;

unsigned long tempoUltimaAtualizacao = 0;                // counter in example code for statusConexao == 5
unsigned long lastTask = 0;                  // counter in example code for statusConexao <> 5

unsigned long  tempoUltimaMudancaFase = 0; //Tempo da Ultima Mudança Fase
unsigned long  tempoUltimaPedidoZPP = 0; //Tempo da Ultima Mudança Fase

byte faseAtualSemaforo = 0;   //Fase atual do Semaforo
byte faseAnteriorSemaforo = -1;   //Fase atual do Semaforo

byte via01Zona = ZONA_OFF;  //Indica qual Zona o TREM esta na via01
byte via02Zona = ZONA_OFF;  //Indica qual Zona o TREM esta na via02
String idTremVia01 = "";    //Id do trem que esta na Via 1
String idTremVia02 = "";    //Id do trem que esta na Via 2



/**
   Função de Inicialização que configura o ESP8266 para ajuste dos pinos de entrada e saída, conforme o hardware.
   Inicializa a serial

*/
void setup() {
  Serial.begin(115200);


  //controle do 595 acionamento dos LEDS
  pinMode(CSpino, OUTPUT);
  pinMode(SW1, INPUT); //botão 1
  pinMode(SW2, INPUT); //botão 2
  pinMode(SW3, INPUT); //botão 3
  pinMode(BUZZER, OUTPUT); //botão 3

  SPI.begin();

  // Inicializa o display
  display.init();
  display.flipScreenVertically();
  display.setFont(ArialMT_Plain_10);
  display.clear();
  drawLogo();
  ligarTodosLeds();
  delay(2000);
  apagarTodosLeds();
  drawNome();
  display.display();
  delay(2000);

  lerPropriedades();

  tempoUltimaMudancaFase = millis();
  faseAtualSemaforo = 0;
  faseAnteriorSemaforo = -1;

  if ((digitalRead(SW1) == LOW)&& (digitalRead(SW2) == LOW)) {
    Serial.println("Reset dos dados de WIFI");
    resetFlashAreaWifi();
  } 

  
}

/**
   Loop principal que faz a chamadas as funcções que operam sem bloqueio do loo principal
*/
void loop() {

  conectar();
  wm.process();

  controlarSemaforo();
  monitorarViaVLT();

  if (digitalRead(SW1) == LOW) {
    Serial.println("drawLogo");
    drawLogo();

  }
  if (digitalRead(SW2) == LOW) {
    drawNome();
  }

  if (digitalRead(SW3) == LOW) {
    tone(BUZZER, 440, 100);
    Serial.print("Id:");
    Serial.println( String(ESP.getChipId()));
    mostrarDisplay("Conectado\nIP: " + WiFi.localIP().toString() + "\nSSID: " + WiFi.SSID() + "\nMQTT State: " + String(mqtt.state()) + "\nCruzamento:" + String(idCruzamento)  );

  }


  delay(10);

}



/**
   Função que implementa a máquina de estados de controle dos semaforos, tratando ONLINE e OFFLine
*/
void controlarSemaforo() {

  if ((WiFi.status() == WL_CONNECTED) && mqtt.connected() && (faseAtualSemaforo == FASE_INICIANDO)) {
    faseAtualSemaforo = FASE_ON_VERMELHO;
  }
  if (( (WiFi.status() != WL_CONNECTED) || !mqtt.connected())  && (faseAtualSemaforo == FASE_INICIANDO)) {
    faseAtualSemaforo = FASE_OFF_SEGURO;
  }

  Serial.println("Fase:" + String(faseAtualSemaforo));

  switch (faseAtualSemaforo) {

    case FASE_INICIO:
      Serial.println("FASE_INICIO");
      if (millis() - tempoUltimaMudancaFase > 10000) {
        faseAtualSemaforo = FASE_INICIANDO;
      } else {
        piscarManutencao();
      }
      break;

    case FASE_INICIANDO:
      Serial.println("FASE_INICIANDO");
      piscarManutencao();

      break;

    case FASE_ON_VERMELHO:
      Serial.println("FASE_ON_VERMELHO");
      if (faseAtualSemaforo != faseAnteriorSemaforo) {
        tempoUltimaMudancaFase = millis();
        faseAnteriorSemaforo = faseAtualSemaforo;
        mostrarLed(LED_FASE_VERMELHO);
      } else {

        Serial.print("Via01:");
        Serial.print(via01Zona);
        Serial.print(" Via02:");
        Serial.println(via01Zona);



        if ( (via02Zona == ZONA_OFF  && via01Zona == ZONA_OFF) && (millis() - tempoUltimaMudancaFase > tempoMaxCruzamentoVia)) {
          Serial.println("FASE_ON_VERMELHO - Zona OFF");
          faseAtualSemaforo = FASE_ON_ALERTA;
          tempoUltimaMudancaFase = millis();
        }

        if ( (via01Zona == ZONA_ZPC  && via02Zona == ZONA_OFF)
             || (via02Zona == ZONA_ZPC  && via01Zona == ZONA_OFF) ) {
          Serial.println("FASE_ON_VERMELHO - ZPC");
          faseAtualSemaforo = FASE_ON_ALERTA;
          tempoUltimaMudancaFase = millis();
        }

        if ((millis() - tempoUltimaMudancaFase > tempoMaxCruzamentoVia) && ( via01Zona == ZONA_ZCV || via02Zona == ZONA_ZCV))  {
          Serial.println("FASE_ON_VERMELHO - Tempo máximo com ZCV");
          via01Zona = ZONA_OFF;
          via02Zona = ZONA_OFF;
          faseAtualSemaforo = FASE_ON_ALERTA;
          tempoUltimaMudancaFase = millis();
          //Tempo máximo do trem na via avisar central
          //TODO: Implementar no futuro
        }

        if ( tempoUltimaPedidoZPP > tempoUltimaMudancaFase) { //indica que teve um ZPP prorrogar prazo
          Serial.println("FASE_ON_VERMELHO - PRORROZANDO PRAZO");
          tempoUltimaMudancaFase = millis();
        }


        if ( millis() - tempoUltimaMudancaFase > tempoMaxCruzamentoVia) { //este if deve sair depois dos testes
          Serial.println("FASE_ON_VERMELHO - Tempo máximo ");
          faseAtualSemaforo = FASE_ON_ALERTA;
          tempoUltimaMudancaFase = millis();
        }
      


      }
      break;

    case FASE_ON_ALERTA:
      Serial.println("FASE_ON_ALERTA");
      if (faseAtualSemaforo != faseAnteriorSemaforo) {
        tempoUltimaMudancaFase = millis();
        faseAnteriorSemaforo = faseAtualSemaforo;
        mostrarLed(LED_FASE_ALERTA);
        tempoTrocadoVia =  millis();
      } else {
        if (millis() - tempoUltimaMudancaFase > tempoAlerta) {
          faseAtualSemaforo = FASE_ON_VERDE;
          tempoUltimaMudancaFase = millis();
        } else {
          piscarVia();
        }
      }

      break;
    case FASE_ON_VERDE:
      Serial.println("FASE_ON_VERDE");
      if (faseAtualSemaforo != faseAnteriorSemaforo) {
        tempoUltimaMudancaFase = millis();
        faseAnteriorSemaforo = faseAtualSemaforo;
        mostrarLed(LED_FASE_VERDE);
      } else if (( !isConectado() && (millis() - tempoUltimaMudancaFase > tempoMinVerde))
                 || (millis() - tempoUltimaMudancaFase > tempoMaxVerde)
                 || ( (via01Zona == ZONA_ZPP || via02Zona == ZONA_ZPP )  && (millis() - tempoUltimaMudancaFase > tempoMinVerde))) {
        faseAtualSemaforo = FASE_ON_AMARELO;
      }

      break;
    case FASE_ON_AMARELO:
      Serial.println("FASE_ON_AMARELO");
      if (faseAtualSemaforo != faseAnteriorSemaforo) {
        tempoUltimaMudancaFase = millis();
        faseAnteriorSemaforo = faseAtualSemaforo;
        mostrarLed(LED_FASE_AMARELO);
        tempoTrocadoPedestre = millis();
      } else {
        if (millis() - tempoUltimaMudancaFase > tempoAmarelo) {
          if (isConectado) {
            faseAtualSemaforo = FASE_ON_VERMELHO;
          } else {
            faseAtualSemaforo = FASE_OFF_SEGURO;
          }

        } else {
          piscarPedestre();
        }
      }
      break;
    case FASE_OFF_SEGURO:
      Serial.println("FASE_OFF_SEGURO");
      if (faseAtualSemaforo != faseAnteriorSemaforo) {
        tempoUltimaMudancaFase = millis();
        faseAnteriorSemaforo = faseAtualSemaforo;
        mostrarLed(LED_FASE_SEGURO);
      } else {
        if (millis() - tempoUltimaMudancaFase > tempoSeguranca) {

          faseAtualSemaforo = FASE_OFF_VERMELHO;
        }


      }


      break;
    case FASE_OFF_VERMELHO:
      Serial.println("FASE_OFF_VERMELHO");
      if (faseAtualSemaforo != faseAnteriorSemaforo) {
        tempoUltimaMudancaFase = millis();
        faseAnteriorSemaforo = faseAtualSemaforo;
        mostrarLed(LED_FASE_VERMELHO);
      } else {
        if (millis() - tempoUltimaMudancaFase > tempoMaxCruzamentoVia) {
          faseAtualSemaforo = FASE_OFF_ALERTA;
        }
      }

      break;
    case FASE_OFF_ALERTA:
      Serial.println("FASE_OFF_ALERTA");
      if (faseAtualSemaforo != faseAnteriorSemaforo) {
        tempoUltimaMudancaFase = millis();
        faseAnteriorSemaforo = faseAtualSemaforo;
        mostrarLed(LED_FASE_ALERTA);
        tempoTrocadoVia =  millis();
      } else {
        if (millis() - tempoUltimaMudancaFase > tempoAlerta) {
          faseAtualSemaforo = FASE_OFF_VERDE;
          tempoUltimaMudancaFase = millis();
        } else {
          piscarVia();
        }
      }
      break;
    case FASE_OFF_VERDE:
      Serial.println("FASE_OFF_VERDE");
      if (faseAtualSemaforo != faseAnteriorSemaforo) {
        tempoUltimaMudancaFase = millis();
        faseAnteriorSemaforo = faseAtualSemaforo;
        mostrarLed(LED_FASE_VERDE);
      } else {
        if ((millis() - tempoUltimaMudancaFase > tempoVerde) ) {
          faseAtualSemaforo = FASE_ON_AMARELO;

        }

      }
      break;

    case FASE_OFF_AMARELO:
      Serial.println("FASE_OFF_AMARELO");
      if (faseAtualSemaforo != faseAnteriorSemaforo) {
        tempoUltimaMudancaFase = millis();
        faseAnteriorSemaforo = faseAtualSemaforo;
        mostrarLed(LED_FASE_AMARELO);
        tempoTrocadoPedestre = millis();
      } else {
        if (millis() - tempoUltimaMudancaFase > tempoAmarelo) {
          if (isConectado) {
            faseAtualSemaforo = FASE_ON_VERMELHO;
          } else {
            faseAtualSemaforo = FASE_OFF_VERMELHO;
          }

        } else {
          piscarPedestre();
        }
      }
      break;
  }
}

/** Retorna true quando conectado, false quando off*/
bool isConectado() {
  return ((WiFi.status() == WL_CONNECTED) && mqtt.connected());
}




//callback de noticação que propriedades precisa ser salva
void saveConfigCallback () {
  Serial.println("Deve salvar as propriedades");
  salvarPropriedades = true;
}

/** Função para salvar as propriedades do sistema de arquivos criado na memória */
void gravarPropriedades() {
  Serial.println("Salvando config");
  DynamicJsonBuffer jsonBuffer;
  JsonObject& json = jsonBuffer.createObject();
  json["mqttServer"] = mqttServer;
  json["mqttPort"]   = mqttPort;
  json["mqttUser"]   = mqttUser;
  json["mqttPass"]   = mqttPass;
  json["idCruzamento"]   = idCruzamento;

  File configFile = SPIFFS.open("/config.json", "w");
  if (!configFile) {
    Serial.println("Falha para abrir o arquivo de config para gravação");
  }

  json.prettyPrintTo(Serial);
  json.printTo(configFile);
  configFile.close();
  //altera flag informando que esse dados já estão salvos
  salvarPropriedades = false;


}
/** Função para remover as propriedades do sistema de arquivos criado na memória */
void removerPropriedades(){
   if (SPIFFS.begin()) {
    Serial.println("Removendo arquivo config.json");
    SPIFFS.remove("/config.json");
    
   }
  
}

/** Função para remover os dados da flash da área de WIFI na memória */
void resetFlashAreaWifi(){
  wm.resetSettings();
  
}



/** Função para ler as propriedades do sistema de arquivos criado na memória */
void lerPropriedades() {
  //read configuration from FS json
  Serial.println("Montando sistema de arquivos FS...");

  if (SPIFFS.begin()) {
    Serial.println("Montado file system");
    if (SPIFFS.exists("/config.json")) {
      //file exists, reading and loading
      Serial.println("lendo arquivo config file");
      File configFile = SPIFFS.open("/config.json", "r");
      if (configFile) {
        Serial.println("Acessando config file");
        size_t size = configFile.size();
        // Allocate a buffer to store contents of the file.
        std::unique_ptr<char[]> buf(new char[size]);

        configFile.readBytes(buf.get(), size);
        DynamicJsonBuffer jsonBuffer;
        JsonObject& json = jsonBuffer.parseObject(buf.get());
        json.printTo(Serial);
        if (json.success()) {
          Serial.println("\nLeitura das propriedades efetuada");

          strcpy(mqttServer, json["mqttServer"]);
          strcpy(mqttPort, json["mqttPort"]);
          strcpy(mqttUser, json["mqttUser"]);
          strcpy(mqttPass, json["mqttPass"]);
          strcpy(idCruzamento, json["idCruzamento"]);
          topicoCruzamento =  TOPICO_CENTRAL_CRUZAMENTO;
          topicoCruzamento += String(idCruzamento);


        } else {
          Serial.println("Falha ao carregar arquivo config json");
        }
      }
    }
  } else {
    Serial.println("Falha na montagem do sistema de arquivos FS");
  }
  //end read

}

/** Assina os Tópicos para comunicação com centro de operações para operação do cruzamento */
void eventosMQTT() {
  Serial.print("Publish a conexão reativada ao MQTT ...");
  // Conectado no MQTT, avisar a central
  mqtt.publish(topicoCruzamento.c_str() , statusCentral);
  // Inscrição para escuta dos eventos para o cruzamento
  mqtt.subscribe((TOPICO_VIA1_CRUZAMENTO + String(idCruzamento)).c_str());
  mqtt.subscribe((TOPICO_VIA2_CRUZAMENTO + String(idCruzamento)).c_str());



}

/** Inicializa o MQTT com sefvidor */
void iniciarMQTT() {
  unsigned short port = (unsigned short) strtoul(mqttPort, NULL, 0);  //COnvert para numero o *char
  mqtt.setServer(mqttServer, port);   //informa qual broker e porta deve ser conectado
  mqtt.setCallback(callbackMQTT);            //atribui função de callback (função chamada quando qualquer informação de um dos tópicos subescritos chega)
  String centraId = "CentralIOTID-";
  centraId += String(idCruzamento);


  mqtt.connect(centraId.c_str());  //validar depois a opção sem usuário ou com conforme as propriedades
  //mqtt.connect(centraId.c_str(), mqttUser.c_str(), mqttPass.c_str());
}

/** Função de tratamento do eventos de mqtt, quando recebe mensagem */
void callbackMQTT(char* topic, byte* payload, unsigned int length) {
  Serial.print("Message recebida [");
  Serial.print(topic);
  Serial.print("] ");
  String msgPayload;
  for (int i = 0; i < length; i++) {
    msgPayload += (char)payload[i];

  }
  Serial.println("msg:" + msgPayload);
  // mostrarDisplay("MQTT recebida \nTópico:\n" + String(topic) + "\nMensagem:\n" +   msgPayload);

  //Convertendo para String para facilitar
  String strTopico = topic;

  if (strTopico.indexOf("via01/ZPP") == 0) {
    via01Zona = ZONA_ZPP;
    idTremVia01 =  msgPayload.substring(0, 4);
    tempoUltimaPedidoZPP = millis();
    Serial.println("Via 01 ZPP Mensagem:" + msgPayload);
    mostrarDisplay("Via 01\nZPP\nMensagem:\n" +   msgPayload);

    return;
  }
  if (strTopico.indexOf("via01/ZCV") == 0) {
    via01Zona = ZONA_ZCV;
    idTremVia01 =  msgPayload.substring(0, 4);
    Serial.println("Via 01 ZCV Mensagem:" + msgPayload);
    mostrarDisplay("Via 01\nZCV\nMensagem:\n" +   msgPayload);
    return;
  }
  if (strTopico.indexOf("via01/ZPC") == 0) {
    via01Zona = ZONA_ZPC;
    idTremVia01 =  "";
    Serial.println("Via 01 ZPC Mensagem:" + msgPayload);
    mostrarDisplay("Via 01\nZPC\nMensagem:\n" +   msgPayload);
    return;
  }
  if (strTopico.indexOf("via02/ZPP") == 0) {
    via02Zona = ZONA_ZPP;
    idTremVia02 =  msgPayload.substring(0, 4);
    tempoUltimaPedidoZPP = millis();
    Serial.println("Via 02 ZPP Mensagem:" + msgPayload);
    mostrarDisplay("Via 02\nZPP\nMensagem:\n" +   msgPayload);
    return;
  }
  if (strTopico.indexOf("via02/ZCV") == 0) {
    via02Zona = ZONA_ZCV;
    idTremVia02 =  msgPayload.substring(0, 4);
    Serial.println("Via 02 ZCV Mensagem:" + msgPayload);
    mostrarDisplay("Via 02\nZCV\nMensagem:\n" +   msgPayload);
    return;
  }
  if (strTopico.indexOf("via02/ZPC") == 0) {
    via02Zona = ZONA_ZPC;
    idTremVia02 =  "";
    Serial.println("Via 02 ZPC Mensagem:" + msgPayload);
    mostrarDisplay("Via 02\nZPC\nMensagem:\n" +   msgPayload);
    return;
  }


}

/** Inicializa o wifi do esp8266 */
void iniciarWIFI() {
  Serial.println("Iniciando WIFI ..."); 

  WiFi.mode(WIFI_STA); // ajustar o modo de operação, esp defaults to STA+AP
  // gotIpEventHandler = WiFi.onStationModeGotIP(wifiObteveIPHandler);
  // disconnectedEventHandler = WiFi.onStationModeDisconnected(wifiDisconectadoHandler);


  //set config save notify callback
  wm.setSaveConfigCallback(saveConfigCallback);

  wm.setConfigPortalBlocking(false);




  if ((digitalRead(SW1) == LOW) && (digitalRead(SW3) == LOW) ) { //se SW1 e SW3 OFF entra no WifiManager
     Serial.println("WIFIManager ativado ..."); 

    wm.setConfigPortalBlocking(true);
    //Se desejar ressetar as configurações via código
    // wm.resetSettings();
    // wm.erase();
 
    WiFiManagerParameter custom_mqtt_server("server", "mqtt server", mqttServer, 40);
    WiFiManagerParameter custom_mqtt_port("port", "mqtt port", MQTTPort, 6);
    WiFiManagerParameter custom_mqtt_user("user", "mqtt user", MQTTUser, 20);
    WiFiManagerParameter custom_mqtt_pass("pass", "mqtt pass", MQTTPass, 20);
    WiFiManagerParameter custom_idcruzamento("idcruzamento", "id cruzamento", IDCruzamento, 4);



    wm.addParameter(&custom_mqtt_server);
    wm.addParameter(&custom_mqtt_port);
    wm.addParameter(&custom_mqtt_user);
    wm.addParameter(&custom_mqtt_pass);
    wm.addParameter(&custom_idcruzamento);


    bool res;
    // res = wm.autoConnect(); // auto generated AP name from chipid
    // res = wm.autoConnect("AutoConnectAP"); // anonymous ap
    res = wm.autoConnect("CentralIOT", "univesp2020"); // password protected ap

    if (!res) {
      Serial.println("Falha para conectar e tempo excedido de espera");
      delay(3000);
      // Se ainda não tiver conectado podemos fazer o reset iniciar tudo novamente
      //ESP.restart();
      //delay(5000);
    }
    else {
      //if you get here you have connected to the WiFi
      Serial.println("Conexão OK WIFI... :)");

      //read updated parameters
      strcpy(mqttServer, custom_mqtt_server.getValue());
      strcpy(mqttPort, custom_mqtt_port.getValue());
      strcpy(mqttUser, custom_mqtt_user.getValue());
      strcpy(mqttPass, custom_mqtt_pass.getValue());
      strcpy(idCruzamento, custom_idcruzamento.getValue());
      topicoCruzamento =  TOPICO_CENTRAL_CRUZAMENTO;
      topicoCruzamento += String(idCruzamento);

      //Salvar as propriedades no FS
      if (salvarPropriedades) {
        gravarPropriedades();
      }
    }



  }





}


/** Função de eventos do wifi - Desconectado */
void wifiDisconectadoHandler(const WiFiEventStationModeDisconnected& event) {
  Serial.printf("T=%d Disconectado (reason=%d)\n", millis(), event.reason);
}
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

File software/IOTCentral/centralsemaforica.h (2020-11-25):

#define MQTTServer       "broker.hivemq.com"
#define MQTTPort         "1883"
#define MQTTUser         "mqtt_user"
#define MQTTPass         "mqtt_pass"
#define IDCruzamento    "9999"


//Tempos das Fases
#define TEMPO_MAXIMO_CRUZAMENTO_VIA  30000
#define TEMPO_MAXIMO_VERDE          180000  
#define TEMPO_ALERTA                  5000  //Tempo de alerta de mudança de fase pedestre e via
#define TEMPO_AMARELO                10000  //tempo AMARELO ON e OFF
#define TEMPO_SEGURANCA               3000
#define TEMPO_VERDE                  30000  //tempo VERDE OFF
#define TEMPO_MAXIMO_ESPERA_VLT      25000
#define TEMPO_MINIMO_VERDE           15000
#define TEMPO_ALERTA_PISCANTE          300



//Tópicos MQTT
#define TOPICO_CENTRAL_CRUZAMENTO   "central/cruzamento/"   ; 
#define TOPICO_VIA1_CRUZAMENTO      "via01/+/"
#define TOPICO_VIA2_CRUZAMENTO      "via02/+/"


#define TEMPO_PISCA 500
#define TEMPO_INTERVALO_ENTRE_RECONECTAR 5000

//Chaves
#define SW1 D0
#define SW2 D3
#define SW3 D4
#define BUZZER D6

#define FASE_INICIO 0
#define FASE_INICIANDO 1
#define FASE_ON_VERMELHO 2
#define FASE_ON_VERDE 3
#define FASE_ON_AMARELO 4
#define FASE_ON_ALERTA 5

#define FASE_OFF_SEGURO 6
#define FASE_OFF_VERMELHO 7
#define FASE_OFF_VERDE 8
#define FASE_OFF_AMARELO 9
#define FASE_OFF_ALERTA 10

#define LED_FASE_VERMELHO 0x16A4
#define LED_FASE_AMARELO 0x2A92
#define LED_FASE_VERDE 0x2949
#define LED_FASE_ALERTA 0x2AA4
#define LED_FASE_MANUTENCAO 0x2A92
#define LED_FASE_SEGURO 0x2AA4

#define ZONA_OFF 9
#define ZONA_ZPP 0
#define ZONA_ZCV 1
#define ZONA_ZPC 2




//Semaforos
//T2 T1 VM VD VM VD VM VD - Byte Superior
//VM VD VM AM VD VM AM VD - Byte Inferior

#define S1_VM 2
#define S1_AM 1
#define S1_VD 0

#define S2_VM 5
#define S2_AM 4
#define S2_VD 3

#define S3_VM 7
#define S3_VD 6

#define S4_VM 9
#define S4_VD 8

#define S5_VM 11
#define S5_VD 10

#define S6_VM 13
#define S6_VD 12

#define VLT1 14
#define VLT2 15


#define CSTR(x) x.c_str()   
#define TXTIP(x) CSTR(x.toString())



void getTime() {
  int tz           = -5;
  int dst          = 0;
  time_t now       = time(nullptr);
  unsigned timeout = 5000;
  unsigned start   = millis();  
  configTime(tz * 3600, dst * 3600, "pool.ntp.org", "time.nist.gov");
  Serial.print("Waiting for NTP time sync: ");
  while (now < 8 * 3600 * 2 ) {
    delay(100);
    Serial.print(".");
    now = time(nullptr);
    if((millis() - start) > timeout){
      Serial.println("\n[ERROR] Failed to get NTP time.");
      return;
    }
  }
  Serial.println("");
  struct tm timeinfo;
  gmtime_r(&now, &timeinfo);
  Serial.print("Current time: ");
  Serial.print(asctime(&timeinfo));
}

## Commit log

2020-10-31 Versão inicial de teste das funcionalidade da placa.
2020-11-10 Versão inicial do Firmware da Central. Esta codificado para conectar Wifi, MQTT e trata reconexão ao cair. Para perfeito funcionamento é necessário adicionar a libs na pasta das bibliotecas do arduin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
2020-11-11 Inicio da máquina de Estados dos semáforos Ainda falta a parte do offline.
2020-11-11 Codificado o estados OFFline .. Agora falta tratar o eventos das zonas de rfid
2020-11-11 Acerto de um bug
    [IOTCentral.ino]
2020-11-22 Essa versão inicial do simulador de VLT. Já esta integrada com MQTT.
2020-11-23 Captura dos evento ZPP,ZCV e ZPC - Falta implementar na maquina de estados.
2020-11-25 Versão com máquina de estados finalizado e operacional.
2020-11-25 Ajuste para cada simulador ter um ID , para multiplas conexões
2020-11-25 Acerto de bug na máquina de estado do semáforo e nova página simulador 4x4
    [IOTCentral.ino, centralsemaforica.h]
2021-01-19 Arquivos da placa pcb e Gerber Kicad 5.0
    [VLTUnivesp-B_Cu.gbr, VLTUnivesp-B_Mask.gbr, VLTUnivesp-B_Paste.gbr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]
2021-01-21 Dicas do ambiente de desenvolvimento
2021-01-21 Link para evento no servidor mqtt padrão
2021-01-21 Adicionei uma função para resetar as configurações de WIFI. Apertando a tecla SW1 + SW2 após o logo
    [IOTCentral.ino]
